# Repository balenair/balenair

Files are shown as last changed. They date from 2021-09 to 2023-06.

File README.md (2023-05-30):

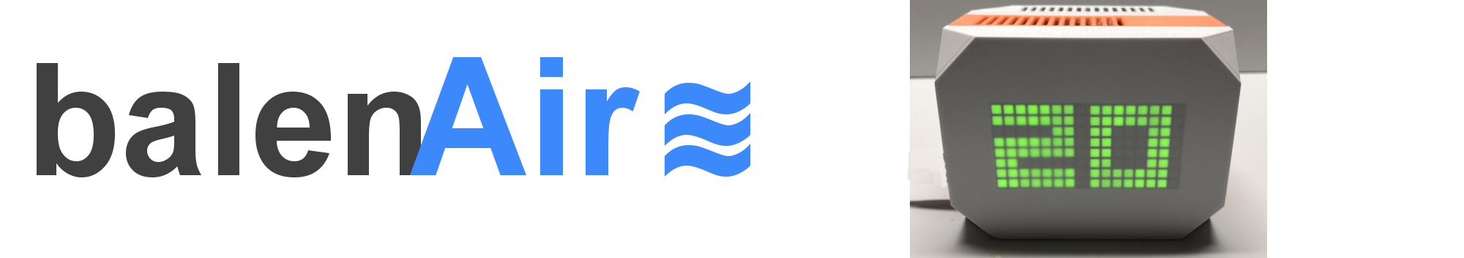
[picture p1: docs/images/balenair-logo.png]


**The IAQ is an attractive device you can easily build that measures the quality of your indoor air and also provides readable feedback on an integrated LED display and a web dashboard.**

## Highlights

- **Works with multiple sensors**: Choose among CO2, particulate matter, temperature/humidity, and VOC sensors based on your needs and budget.
- **Multiple display options**: Choose either a bi-color LED matrix or a multi-color LED bargraph.
- **Your data stays local**: Your data remains your own. It is stored locally and can be accessed by a built-in secure web dashboard.

## Setup and configuration

Start by assembling the hardware - see our parts list and assembly instructions in [the docs](./docs). Deploying the code to a fleet of one or more devices is as easy as clicking the button below:

balena deploy button (https://dashboard.balena-cloud.com/deploy?repoUrl=https://github.com/balenair/balenair)

## Documentation

Head over to [our docs](./docs) for detailed parts lists, options, building, installation and usage instructions, customization options and more!

## Motivation

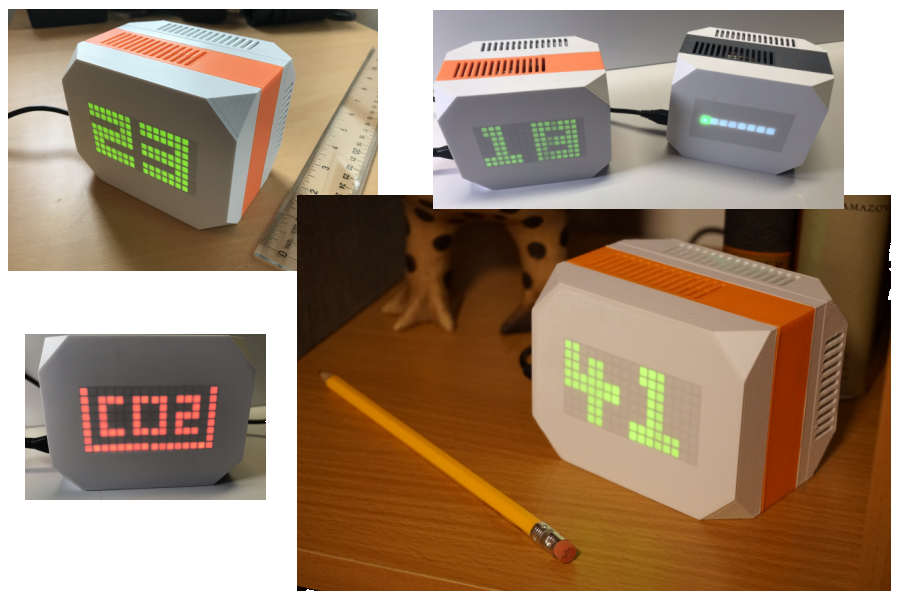
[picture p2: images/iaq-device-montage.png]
concept


balenAir is a great starter project for learning about IoT, environmental sensors, containers, and the balena platform. It is also a very functional and useful device, which stores all of your data locally, not in the cloud. Yet you can access this data anywhere via its built-in web server and secure VPN tunnel.

This open source project is in active development so if you have any feature requests or issues please submit them here on GitHub. PRs are welcome, too.

## The IAQ score
The IAQ device uses a combination of CO2, VOC, and particulate sensors to generate an indoor air quality score.  The standard IAQ device displays the score using an LED matrix on the front of the unit. The easy-to-remember score ranges from 0 (best air quality) to 99 (hazardous air quality).

### The sensors
The project consists of up to three sensors but only one is required. You can choose any or all depending on your needs and budget. The air quality score is comprised of a combination of readings from the available sensors. 

- Particulate sensors for smoke, dust, pollen and other tiny particles
- CO2 sensor for exhaled breath and burning fossil fuels
- Volatile Organic Compound (VOC) sensor for gasses emitted by solid and liquid products
- Temperature and humidity environmental sensors

Since all of the sensors utilize an I2C Qwiic connector, no soldering is required. See the [parts list](./docs/01-hardware-selection.md#choosing-your-sensors) in the documentation for more details on cost and availability of these sensors.

### The display

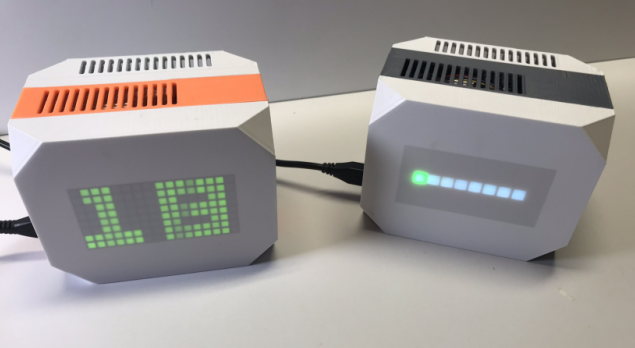
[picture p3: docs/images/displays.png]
IAQ displays


The standard display uses two 1.2" Bi-color 8x8 LED Matrix displays that cost about $16 each ($32 total). This display provides visual feedback of the air quality score and changes color as the score increases. A less costly option utilizes an eight segment multi-color LED bargraph that displays the air quality score as a horizontal graph that also changes color as the score changes. 

The standard matrix display requires some soldering to build. The bargraph LED version can be built without any soldering.

You can build a working IAQ device for as little as $50! See the parts list in the [Hardware Selection Guide](./docs/01-hardware-selection.md) for more details on cost and availability of the display parts.

### The case

We provide STL files so you can use a 3D printer to print a beautiful case for the IAQ.

The case consists of four interlocking layers that are held together by four M3 x 40mm hex socket head screws. The case accomodates any or all of the supported sensors, two different Raspberry Pis, as well either of the display options.

See [the documentation](./docs/05-case-printing-and-assembly.md) for more information about printing and assembly of the case.

### The software

All of our software is open source so you can inspect it in this repository before you decide to build or purchase a device. The system is built on the [balena](www.balena.io) IoT platform which ensures easy software updates, secure URL access, and ease of maintenance.

## Getting Help

If you're having any problem, please [raise an issue](./issues/new) on GitHub and we will be happy to help.

## Contributing

Do you want to help make IAQ better? Take a look at our [Contributing Guide](CONTRIBUTING.md). Hope to see you around!

## License

IAQ is free software, and may be redistributed under the terms specified in the license.

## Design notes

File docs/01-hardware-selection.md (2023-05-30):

# 1. Hardware selection

There are a number of options when it comes to selecting hardware for the IAQ. Cost, availability and performance are some factors to consider when choosing the parts below.

## Choosing your Pi

The IAQ runs on a Raspberry Pi, so you'll need one of the following compatible devices:

- A [Pi 3A+](https://www.raspberrypi.com/products/raspberry-pi-3-model-a-plus/) or [Pi Zero 2 W](https://www.raspberrypi.com/products/raspberry-pi-zero-2-w/) will fit in the custom case, so one of these is the best choice
- A [Pi 3B](https://www.raspberrypi.com/products/raspberry-pi-3-model-b/), [Pi 3B+](https://www.raspberrypi.com/products/raspberry-pi-3-model-b-plus/), [Pi 4](https://www.raspberrypi.com/products/raspberry-pi-4-model-b/), [CM4](https://www.raspberrypi.com/products/compute-module-4/?variant=raspberry-pi-cm4001000) or [CM3+](https://www.raspberrypi.com/products/compute-module-3-plus/) based system (Like the [balenaFin](https://www.balena.io/fin/)) will work fine but will not fit in the custom case.

(The IAQ is not compatible with the Pi Zero or first generation Pi)  

The IAQ is not particularly resource-intensive, so any of the supported boards above should work equally well. Note that currently the Pi Zero 2 W is only available without headers soldered in place. If you choose this device, you'll need to solder headers or wires onto the board. You could also try a "[solderless hammer header](https://shop.pimoroni.com/products/gpio-hammer-header?variant=35643318026)" although we have not tested these.

## Choosing your sensors

The sensors evaluate your air and return data that is used to deterime your air quality score. The IAQ utilizes the [big sensor block](https://github.com/alanb128/big-sensor) so supports any of the sensors listed [here](https://github.com/alanb128/big-sensor#currently-supported-sensors). However, you'll want to use a supported sensor that returns one or more of the following values:

- CO2
- eCO2
- temperature
- humidity
- pm100 env
- pm25 env

 Typically, one or more of the following sensors are used, depending on your budget and air quality analysis needs.

| Sensor | Detects | Description | cost (USD) | specifications (approx.) |
| --- | --- | --- | --- | --- |
| [PMSA003I](https://www.adafruit.com/product/4632) | Smoke, dust, dirt, pollen particles | laser-scattering type | $44.95 | 0.3-1.0,1.0-2.5, 2.5-10 Micrometer particles ([datasheet](https://cdn-shop.adafruit.com/product-files/4632/4505_PMSA003I_series_data_manual_English_V2.6.pdf)) |
| [SCD-40](https://www.adafruit.com/product/5187) | Exhaled breath and burning fossil fuels |  CO2 photoacoustic sensor CO2 (plus temp and humidity) | $44.94 | 400 - 2000 PPM ([datasheet](https://cdn-learn.adafruit.com/assets/assets/000/104/015/original/Sensirion_CO2_Sensors_SCD4x_Datasheet.pdf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)) |
| [SGP-30](https://www.adafruit.com/product/3709) | Gasses emitted by solid and liquid products  |  VOC (and eCO2) Hot-plate MOX sensor | $17.50 | eCO2 400-60,000 ppm, TVOC 0-60,000 ppb ([datasheet](https://cdn-learn.adafruit.com/assets/assets/000/050/058/original/Sensirion_Gas_Sensors_SGP30_Datasheet_EN.pdf)) |
| [ENS160](https://www.adafruit.com/product/5606) | Gasses emitted by solid and liquid products  |  VOC (and eCO2) MOX gas sensor | $21.95 | eCO2 400-65,000 ppm, TVOC 0-65,000 ppb ([datasheet](https://cdn-learn.adafruit.com/assets/assets/000/115/331/original/SC_001224_DS_1_ENS160_Datasheet_Rev_0_95-2258311.pdf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)) |

All of these sensors use the popular I2C protocol to communicate with the Pi and include [Qwiic](https://www.sparkfun.com/qwiic) connectors so you don't need to do any soldering to use these sensors.

The IAQ will automatically detect which sensors are present and caluclate the air quality score accordingly. If you connect the specified VOC sensor but do not have the specified CO2 sensor attached, the VOC sensor's eCO2 readings will be reported as the CO2 values. (eCO2 is generally less accurate than CO2 and requires proper calibration)

## Choosing your display

IAQ displays

Each IAQ device has a bright LED display so you can read your score from across a room. The score will be calculated and displayed even if your device is not connected to the internet. Regardless of the display type you choose, you can still obtain detailed sensor and air quality score readings from the built-in web dashboard.

### Two digit bi-color LED matrix

This is the most detailed display and also the most expensive. It utilizes two $15.95 [LED Square Pixel Matrix with I2C Backpack](https://www.adafruit.com/product/902) boards which require some light soldering to mount the display to the backpack. Recent versions of the backpack include a qwiic connector, but older ones will need to use angled headers, not the straight ones included with the boards. These should be right-angled male headers where the right angle occurs above the plastic strip [like these](https://www.amazon.com/Uxcell-a15062500ux0349-Single-40-pin-Breadboard/dp/B01461DQ6S/), NOT below the strip [like these](https://www.adafruit.com/product/1540). (A subtle difference but one type will fit in the case while the other will not!) 

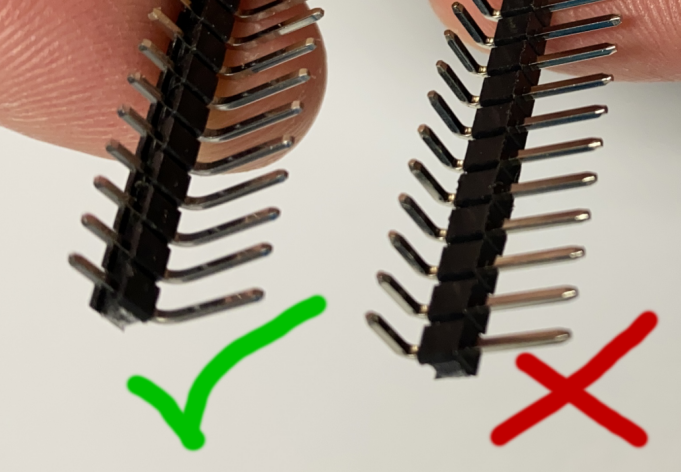
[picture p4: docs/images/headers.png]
headers


If you are not using our custom case, you can just use the headers that are included with the display boards. These displays can be mounted directly on posts in the custom case with no modifications required.

The matrix displays are driven via I2C and if they do not have qwiic connectors, will require two [Qwiic to female header](https://www.adafruit.com/product/4397) cables to connect to the Pi. 

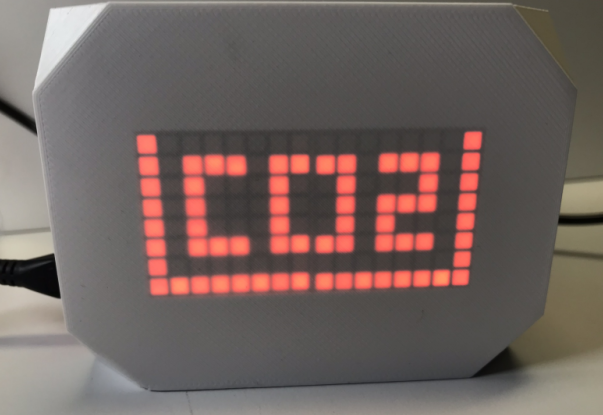
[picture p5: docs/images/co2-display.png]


In addition to displaying the two digit score, these displays can optionally show the most dominant pollutant type (CO2, PM10, PM2.5, VOC) detected by the sensors, as well as some rudimentary animations. The displayed information will change color from green to orange to red depending on the score.

To summarize the parts for this option:

- Two [LED Square Pixel Matrix with I2C Backpack](https://www.adafruit.com/product/902)

- One [50mm QT to QT cable](https://www.adafruit.com/product/4399) to connect the first LED to the second.

If the backpack does not include qwiic connectors:

- One strip of [angled male headers](https://www.amazon.com/Uxcell-a15062500ux0349-Single-40-pin-Breadboard/dp/B01461DQ6S/)

- One additional [Qwiic to female header](https://www.adafruit.com/product/4397) cable to connect the second backpack to the multiport

- One SparkFun Qwiic multiport, available [here](https://www.adafruit.com/product/4861) and [here](https://www.sparkfun.com/products/18012)

### Eight LED multi-color bargraph

This type of display is less detailed than the two digit matrix (the score is broken into eight segments with each one representing 12.5 points) and can't display the pollutant type. It does however have multiple color indications and can be configured in three different display formats. No soldering is required with this option

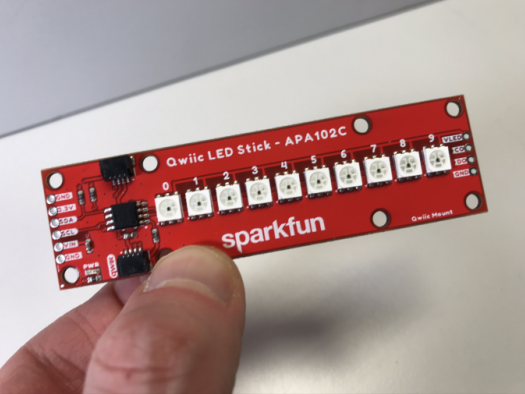
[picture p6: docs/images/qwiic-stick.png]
Qwiic Stick


This display is $11 or about a third the cost of the LED matrix and is based on the 10 LED [SparkFun Qwiic Stick](https://www.sparkfun.com/products/18354). (We only use eight of the ten LEDs that neatly fit the IAQ's case window.) In addition to one of these displays, you'll need a [100mm QT to QT cable](https://www.adafruit.com/product/4210) to connect it to the IAQ.

With this option, you'll also need a SparkFun Qwiic multiport, available [here](https://www.adafruit.com/product/4861) and [here](https://www.sparkfun.com/products/18012)

## Remaining parts list

With either display, you'll also need the following parts:

- One [Qwiic to female header cable](https://www.adafruit.com/product/4397) to connect the display to the Pi

- One [200mm QT to QT cable](https://www.adafruit.com/product/4401) to connect the display to the first sensor.

- One [100mm QT to QT cable](https://www.adafruit.com/product/4210) to connect the first sensor to the second sensor. Only required if you have two or three sensors!

- Another [100mm QT to QT cable](https://www.adafruit.com/product/4210) to connect the second sensor to the third sensor. Only required if you have three sensors!

Note that there are some additional hardware requirements if you will be using the custom 3D printed case - see [this section](05-case-printing-and-assembly.md) for details.

### NEXT
[2. Hardware Setup](02-hardware-setup.md)

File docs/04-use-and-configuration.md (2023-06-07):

# 4. IAQ usage and configuration

After you have put together the hardware, installed the software and (optionally) assembled the case, you can power on the IAQ by plugging a standard 5V/2.5A or greater power transformer into the Pi's micro USB port. After about a minute, the air quality score should be visible on the display. Sensor readings are taken approximately once per minute.

## The IAQ score

The easy-to-remember IAQ score ranges from 0 (best air quality) to 99 (hazardous air quality). Each sensor has a range of readings that are categorized as "good", "moderate", or "unhealthy". These rages are based in part on various governmental standards, such as [the EPA](https://www3.epa.gov/region1/airquality/pm-aq-standards.html) and others.

| Reading | Description | Sensor Type | good range (0 - 50) | moderate range (51 - 74) | unhealthy range (75 - 99) |
| --- | --- | --- | --- | --- | --- |
| PM2.5 | Smoke, dust, dirt, pollen | PMSA003I | 12 - 34 ug/m3 | 35 - 54 ug/m3 | 55+ ug/m3 |
| PM10 | Dust, smoke, exhaust, tiny particles | PMSA003I | 0 - 53 ug/m3 | 54 - 149 ug/m3 | 150+ ug/m3 |
| CO2 | Exhaled breath and burning fossil fuels | SCD-40 | 400 - 999 PPM | 1000 - 1999 PPM | 2000+ PPM |
| VOC | Gasses emitted by solid and liquid products  | SGP-30 | 0 - 499 PPB | 500 - 999 PPB | 1000+ PPB |

**The final score displayed by the device is the highest score from among all the available sensors.**

## Display options

### LED Matrix display
By default, the display will constantly show the score if the value is below 50. Once the score is over 50, an icon representing the dominant pollutant will alternate on the display along with the score. These icons are:

- "CO2" representing carbon dioxide (CO2)
- "PM1" representing PM 10 (particulate matter 10 micrometers or less in diameter)
- "PM2" representing PM 2.5 (particulate matter 2.5 micrometers or less in diameter)
- "VOC" representing Volatile Organic Compunds (VOC)

When you first power on the device, it will cycle through the connected sensors and briefly display the icon above for each one found. If no sensors are found, the display will show "??". 

You can change the default behavior of the icon display by setting the following [device variables](https://www.balena.io/docs/learn/manage/variables/#device-variables) in your balenaCloud dashboard:

`ALERT_LEVEL` changes the threshhold value for alternating the display of the pollutant. The default value is 50 but you can change it by setting this value. 

`ALERT_MODE` has a default value of `1`, which causes the display to alternate the pollutant icon when the score exceeds the `ALERT_LEVEL` defined above. Changing this value to `0` will cause the score to always be displayed and never display a pollutant icon regardless of the `ALERT_LEVEL`. Setting this value to 2 will always show an alternating pollutant icon regardless of the `ALERT_LEVEL`.

Note that these variables will not initially be present in the dashboard, you will have to add them if you want to change their value. If they have not been added, or you delete them after previously adding them, they will revert back to the default values mentioned above.

The display changes color based on the score as follows:

| Score range | Description | LED display color | 
| --- | --- | --- |
| 0 - 49 | Good air quality | green |
| 50 - 74 | Moderate air quality | orange |
| 75 - 99 | Unhealthy air quality | red |

### LED bargraph display

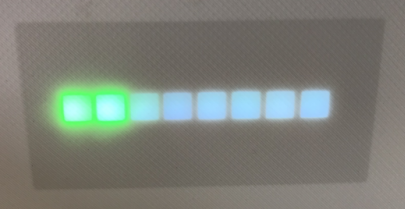
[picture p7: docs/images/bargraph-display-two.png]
Bargraph


By default the bargraph display will illuminate a segment from left to right based on the IAQ score, with each segment representing 12.5 points. The segments will be lit according to the color scheme shown above for the matrix display. Any unused segments to the right will be slightly illuminated in white. To eliminate the white segments, set the device variable `BAR_MODE` to `0`.

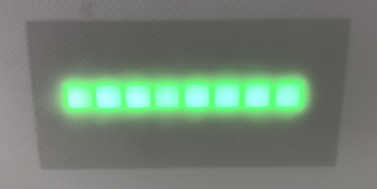
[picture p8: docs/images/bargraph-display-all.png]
Bargraph


If you set the `BAR_MODE` to `2` all of the LED segments will always be illuminated in either green, yellow, or red depending on the IAQ sore as shown above. 

To reset the display to the default mode, set `BAR_MODE` to `1` or delete the variable.

If the score is zero and you are using display mode 2, no LED segments will be illuminated. To force the leftmost LED segment to be lit even if the score is zero, set the `ZERO_BAR` variable to a value of `1`.

Upon initial startup, if no sensors are detected the bargraph display will show alternating red and green segments.

## The IAQ dashboard
The IAQ dashboard is a pre-built [Grafana](https://grafana.com/grafana/) dashboard that shows you the current and historical values from all of your sensors as well as the air quality score over time. If you are on the same network as the device, you can browse to IAQ.local or to the local IP address of the device (which you can find on its balenaCloud dashboard) to see the dashboard. If you want to enable access to the IAQ dashboard from outside your network, you can enable the "Public Device URL" from your balenaCloud dashboard and then click the icon next to that switch to view its public URL.

To modify the IAQ dashboard or add your own, you can log into Grafana with the arrow icon in the lower left of the screen. The default username and password are admin/admin. If you want to experiment with making changes to the dashboard, you can copy the default dashboard and make changes to it so you don't risk making inadvertent alterations.

See the [Grafana documentation](https://grafana.com/docs/grafana/next/panels/working-with-panels/) for more information about modifying/designing dashboards.

## Other configuration options

### Logging
By default, the IAQ service will only send certain information to the logs. If you want to see more or less detail in the logs, you can set the `LOG_LEVEL` device variable. The default value is `WARNING` but setting to `DEBUG` or `INFO` will provide more logging detail. To see fewer logging details, you can select `ERROR` or `CRITICAL` as well.

### External MQTT

You can have the balenAir publish to an external MQTT broker or service, such as the [balenAir Aggregator](https://github.com/balenair/aggregator). To initiate this, set the `AGG_ADDRESS` variable to the address of the external MQTT broker - this works best if all devices are on the same local network. See the Aggregator repo for more details on other setup options. You can also specify `AGG_USERNAME`, `AGG_PASSWORD`, and `AGG_PORT` (default is 1883) as well. To stop publishing, delete the `AGG_ADDRESS` variable.

## VOC calibration
The [SGP30 VOC sensor](https://www.adafruit.com/product/3709) is a type of gas sensor that needs to be calibrated to provide reasonably accurate measurements. The balenAir no longer stores a baseline for this sensor, so see the details [here](https://learn.adafruit.com/adafruit-sgp30-gas-tvoc-eco2-mox-sensor/circuitpython-wiring-test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) regarding its default calibration process.

### NEXT
[Case printing & assembly](05-case-printing-and-assembly.md)

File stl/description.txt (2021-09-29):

Files for printing the four pieces that make up the custom case.

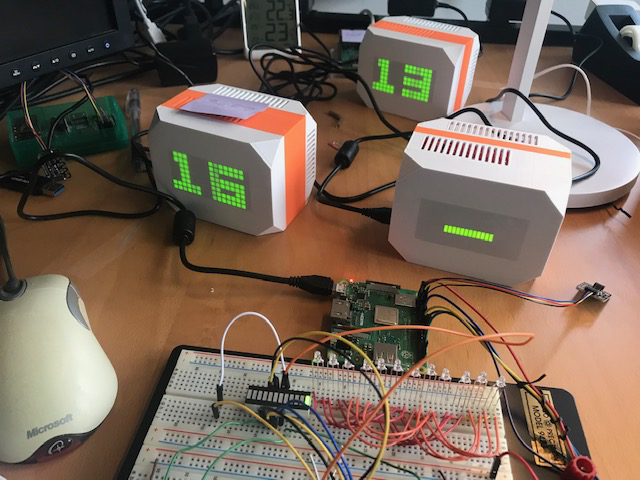
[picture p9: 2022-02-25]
images/three-iaq-displays.png

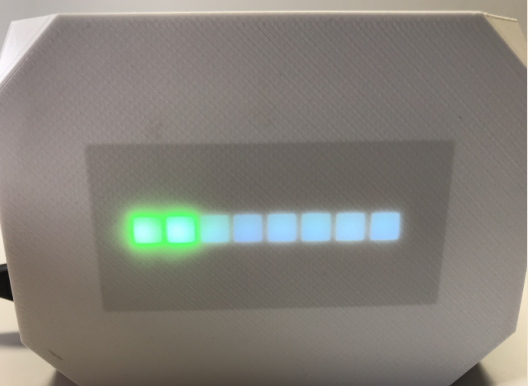
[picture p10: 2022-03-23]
docs/images/bargraph-1.png

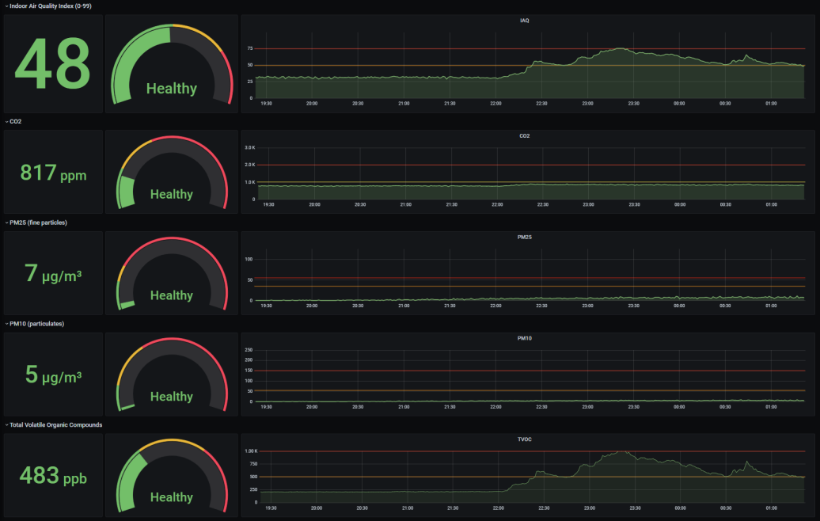
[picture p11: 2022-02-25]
docs/images/dashboard.png

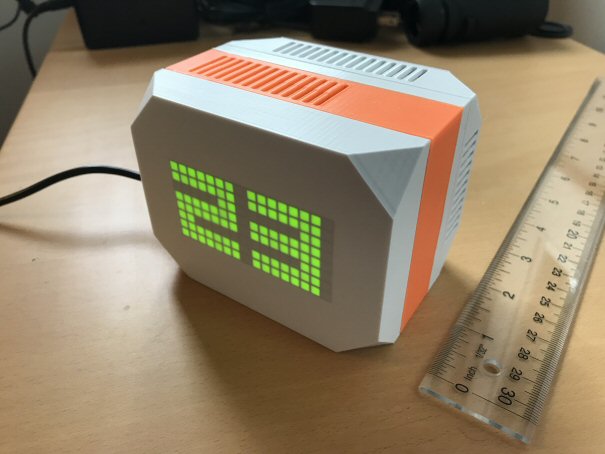
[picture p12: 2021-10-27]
images/unit2.jpg

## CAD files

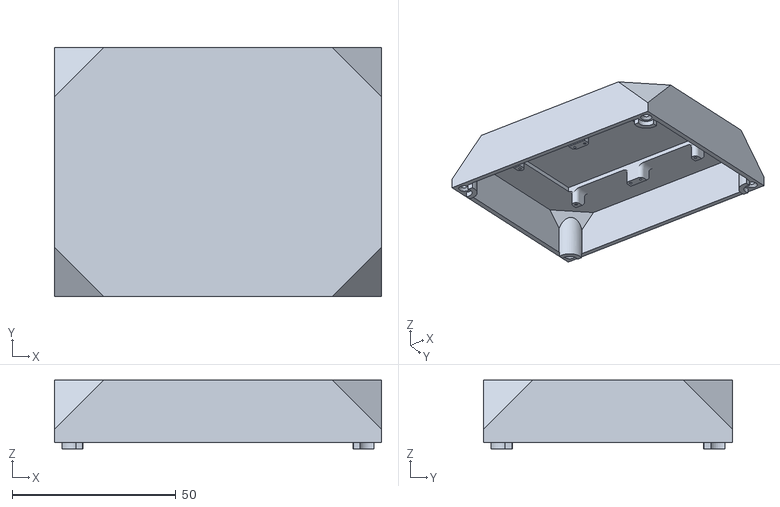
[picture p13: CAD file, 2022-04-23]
stl/front.stl
100.0 x 76.0 x 21.0

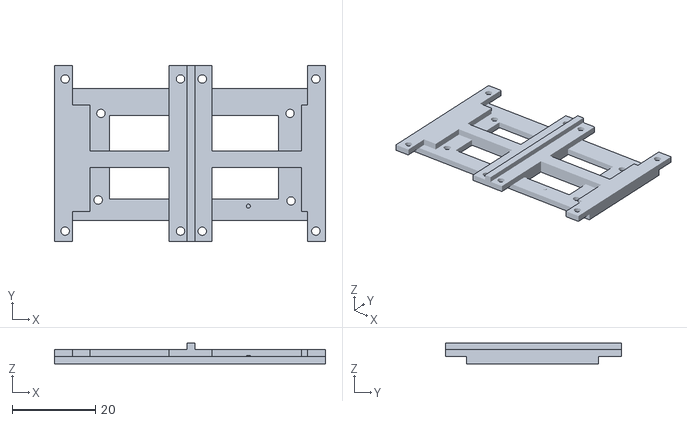
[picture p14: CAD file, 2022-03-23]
stl/bargraph-bracket-back.stl
65.0 x 42.2 x 5.00

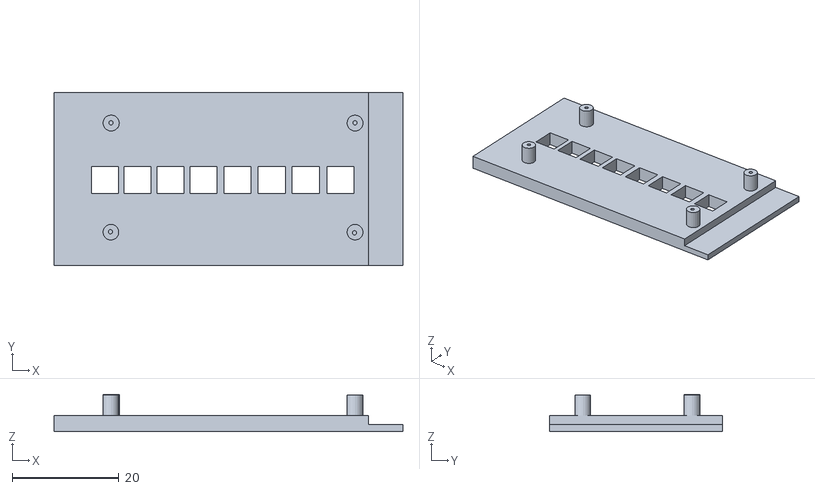
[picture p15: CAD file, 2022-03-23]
stl/bargraph-bracket-front.stl
65.5 x 32.5 x 6.96

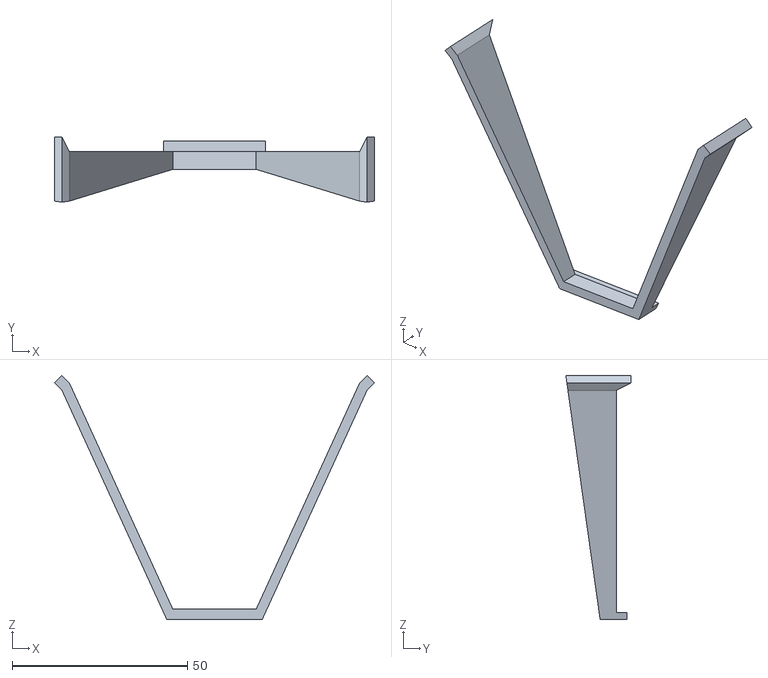
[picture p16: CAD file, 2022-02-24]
stl/stand.stl
91.4 x 18.7 x 69.7

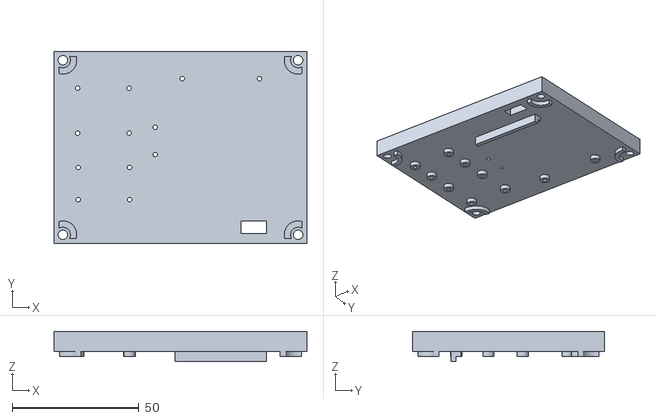
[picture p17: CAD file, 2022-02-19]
stl/insulate_sense.stl
100.0 x 76.0 x 12.0

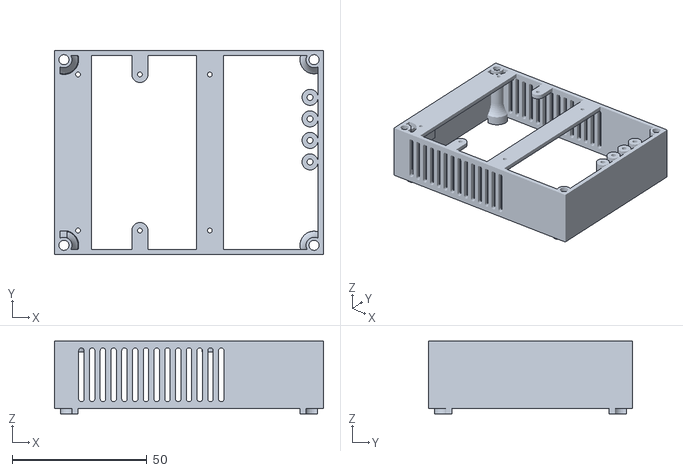
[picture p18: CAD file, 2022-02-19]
stl/pi_ring.stl
100.0 x 76.0 x 27.0

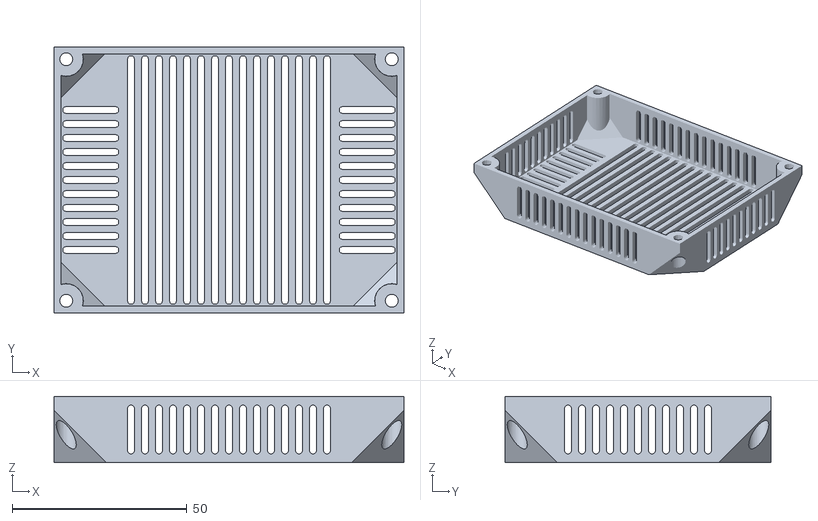
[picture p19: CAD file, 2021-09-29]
stl/back.stl
100.0 x 76.0 x 19.0

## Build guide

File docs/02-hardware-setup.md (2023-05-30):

# 2. Hardware setup

Once you have all of your parts gathered, it's a good idea to walk through this assembly guide to get familiar with how everything is connected together. Even if you will be using the 3D printed case, you may want to connect everything together and install the software before placing everything in the case. All of the connections are modular so it's easy to disconnect all of the parts and re-connect them again later inside the case. Make sure your Pi is powered off during the hardware setup!

## Connecting the sensors

All of the sensors utilize the I2C data bus and contain Qwiic connectors, so they can all be connected together rather easily. 

Start by connecting the female jumpers on one end of the "150 mm Qwiic to 4 pin female cables" to the Raspberry Pi. Note the pin assignments based on the wire color using the diagram below:

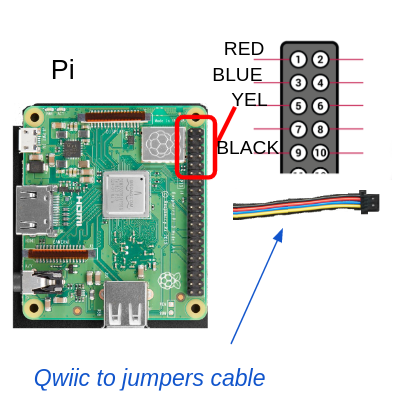
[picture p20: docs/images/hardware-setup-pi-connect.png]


- The red wire goes to pin 1 (3v)
- The blue wire goes to pin 3 (SDA)
- The yellow wire goes to pin 5 (SCL)
- The black wire goes to pin 9 (Gnd)

The connector at the other end of the cable connects to either the first matrix display or any one of the four ports on the multiport connector if required. Now connect one end of the "200mm QT to QT cable" to any of the three remaining empty ports on the multiport connector or the second matrix display. This is the long cable that will be used to connect to the first sensor since when mounted in the case, the multiport will be somewhat far from this sensor. The other end of this cable can be connected to the first sensor. When mounted in the case, the first sensor is physically the blue rectangular particulate sensor. However, you can connect the sensors in any order you please. Use the remaining "QT to QT" cables to connect any remaining sensors you may have in a daisy chain fashion as shown below:

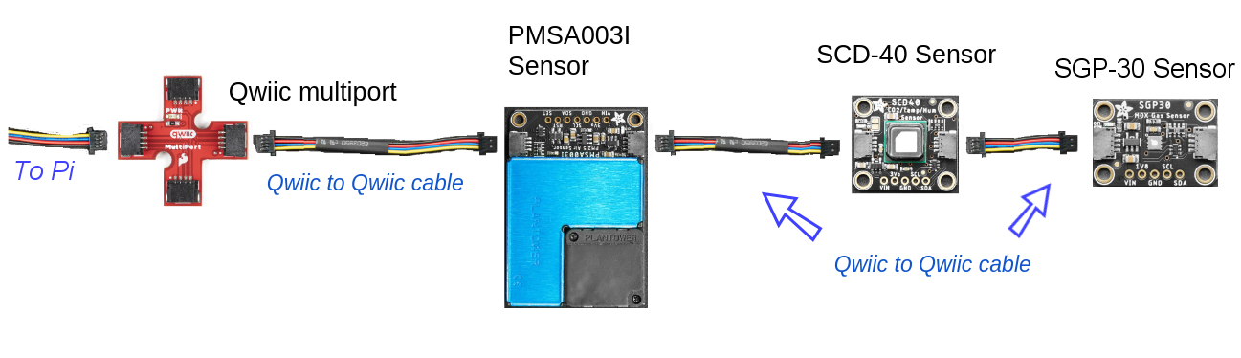
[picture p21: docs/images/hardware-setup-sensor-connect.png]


## Connecting the display

### LED matrix assembly

If you're using the two LED matrix boards, you'll first need to solder each LED matrix to its backpack as described [here](https://learn.adafruit.com/adafruit-led-backpack/bi-color-8x8-matrix-assembly). 

You'll also need to change the I2C address of one of the displays. using [this guide](https://learn.adafruit.com/adafruit-led-backpack/changing-i2c-address), solder together the A0 pads of one display to change its address from 0x70 to 0x71. This will be the left digit when facing the front of the two displays.

If your backpack does not have qwiic connectors:

Solder the four pin male headers to each backpack. If you will be using the standard case, you must use the angled headers as specified in the parts list, not the straight headers included in the backpack kit. Make sure the headers are angled outwards as shown below:

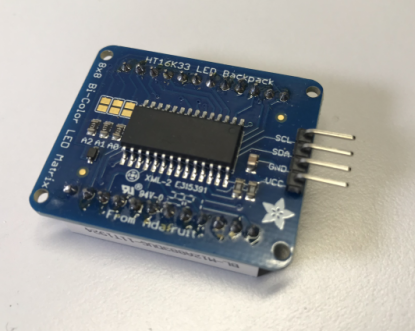
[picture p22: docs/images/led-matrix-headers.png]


Finally, use the two remaining "Qwiic to female jumper" cables to connect the two displays to the two open ports on the multiport connector. The jumper cables connect to the headers as follows:

- The yellow jumper connects to SCL
- The blue jumper connects to SDA
- The black jumper connects to GND
- The red jumper connects to VCC

### LED bargraph display

Connecting this type of display is easy: simply connect one end of a 100mm Qwiic connector to one of the jacks on the LED stick. Connect the other end to a free port in the 4-way Qwiic multiport connector.

NOTE: This display has a power LED that may be visible through the IAQ case. You should disable this LED by scratching off the trace between the LED pads (not the VLED pads!) on the back of the circuit board. See the [Qwiic Stick guide](https://learn.sparkfun.com/tutorials/qwiic-led-stick---apa102c-hookup-guide#hardware-overview) for more details.

### Next
[3. Software setup](03-software-setup.md)

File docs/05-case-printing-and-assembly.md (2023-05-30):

# 5. Case printing and assembly

The IAQ has a lovely and easy-to-print 3D case that fits the standard parts listed in the hardware list.

## Hardware required

To assemble the printed parts, you'll need the following:

- eight (8) M1.4 x 5mm self-tapping screws to mount the display (plus four more if using the LED bargraph)
- four (4) M2 x 6mm pan head screws for mounting the Pi 3A+ or four (4) M2 x 10mm screws for Pi Zero 2W
- two (2) M2 x 10mm pan head screws for mounting the multiport connector
- two to four (2 - 4) M2 x 12mm pan head screws to mount EACH sensor (up to 10 screws total)
- four (4) M3 x 40mm hex socket head screws to secure the case

The screw lengths specified above for the M2 screws are minimum values. Somewhat longer screws can always be used instead; shorter screws may not work well. In a pinch, #2 screws of similar length may be substituted for the M2 screws although they may be a bit tight.

## Printing

The IAQ case consists of four pieces that can be printed using a standard consumer 3D printer. The files for printing these pieces are in the `stl` folder.



We have tested these pieces by slicing them using Ultimaker Cura 4.11; Each piece should be rotated 180 degrees for printing. We used an infill density of 20%, which the printing characteristics below are based on.

## Front piece

The front panel holds the LED/backpack assemblies. Each assembly sits on a set of four posts. Use M1.4 x 5mm screws to secure the displays to the posts. The backpack that is set to the 0x71 address by the solder pad blob should be on the right when looking at the back of the face plate. The angled headers should face upwards towards the top of the front piece. (At this point, you can establish which orientation is the top, as the sides are both the same.) TIP: attach the qwiic connectors (or female wire headers) before inserting the displays onto the posts.

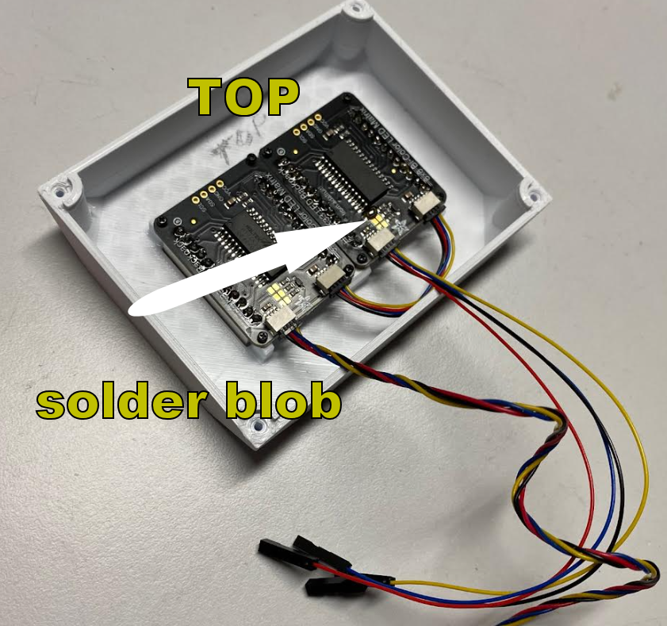
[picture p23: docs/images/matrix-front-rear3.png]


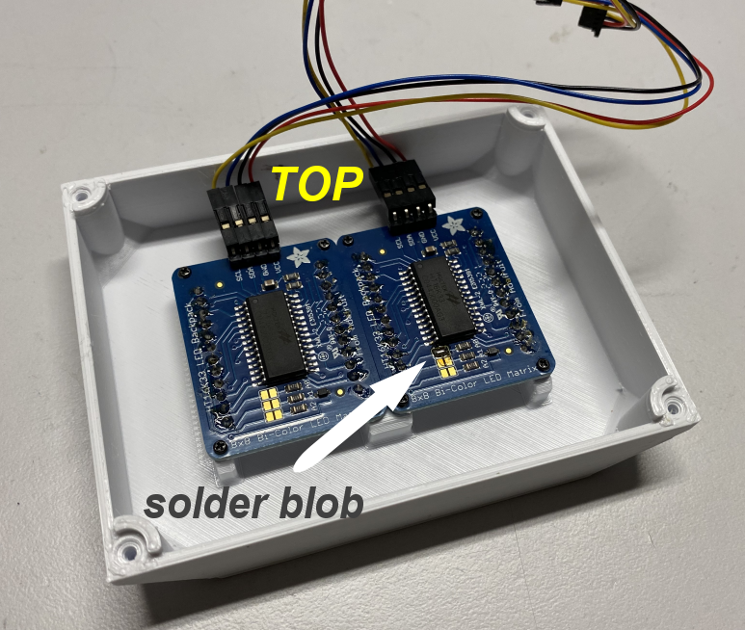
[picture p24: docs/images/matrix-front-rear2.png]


Printing tips: Note that the first layer is only one layer thick for the display window portion of the front piece. Since that adds a lot of surface area on the bed, you can probably get by with a skirt instead of a brim for this part. We suggest printing this piece in some version of white so that the window does not interfere with the LED colors. (Our standard has been to print the front and back in white, and the middle pieces in a contrasting color such as orange.) Typical printing characteristsics: 28g/9.4m of filament; 4:06 print time.

### LED Bargraph
If you are using the LED bargraph, also print the `bargraph-bracket-front.stl` and `bargraph-bracket-back.stl` pieces. Start by laying the front bracket piece (with the square cutouts) flat with the posts facing up and the indented area on the left. Then place the Qwiic Stick upside down onto the four posts as shown below:

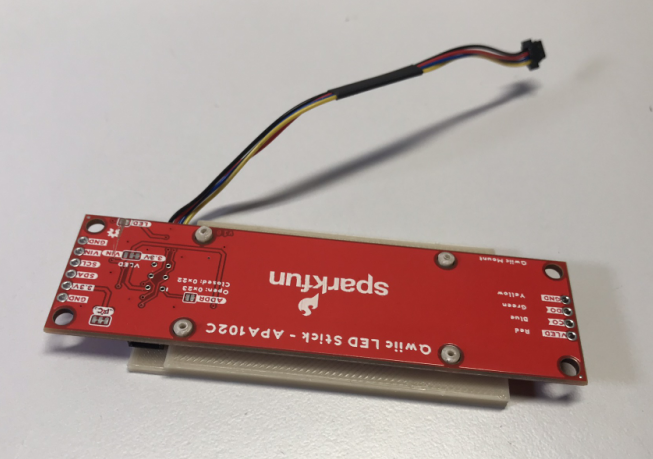
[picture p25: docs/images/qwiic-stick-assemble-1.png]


Next, place the back bracket piece on top of the four posts fron the front piece, lining up the four holes. Note that the wider side of the back bracket (with the black marker in the image below) should be on the right. Use four M1.4 x 5mm self-tapping screws to secure the two parts of the bracket together with the Qwiic Stick in between.

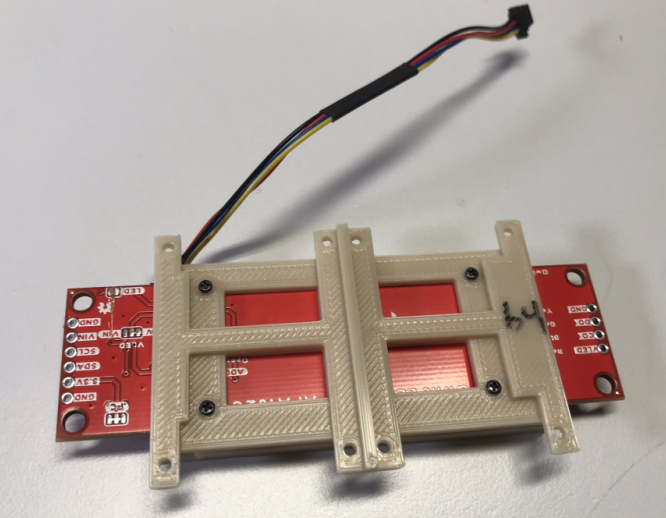
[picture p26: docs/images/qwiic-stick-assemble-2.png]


Now use eight M1.4 x 5mm self-tapping screws to attach the bracket assembly to the front case piece, noting the orientation shown below:

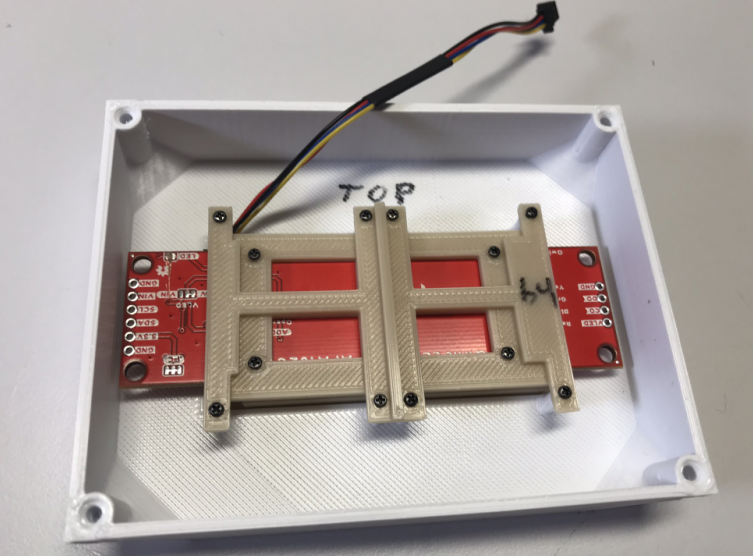
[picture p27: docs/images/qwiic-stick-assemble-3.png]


## Pi Ring
The `pi_ring` holds the Raspberry Pi 3A+ or Zero 2 W in place. 

### Pi 3A+
Use four M2 screws to mount the Pi in the provided holes and secure with nuts oriented as shown below. Make sure the micro USB port lines up with the hole on the side of the pi ring.

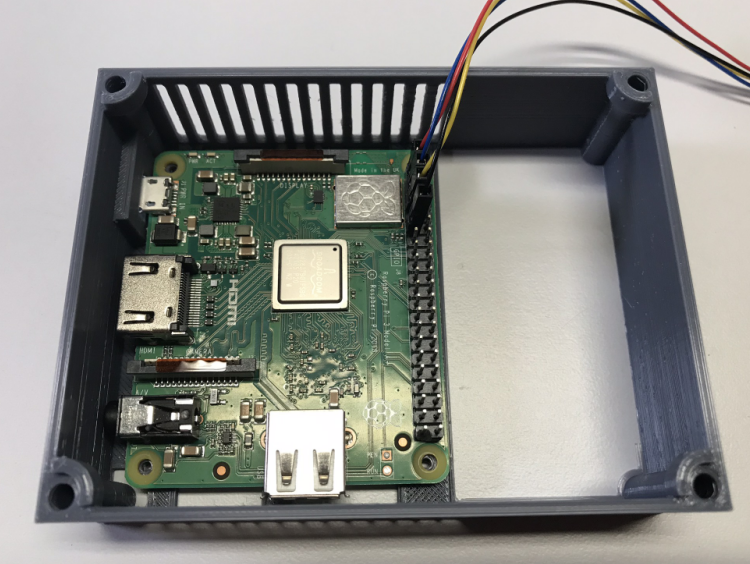
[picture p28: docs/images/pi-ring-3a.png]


### Pi Zero 2W
Note the four cylidrical spacers that print along the right wall of the part. These are used to properly mount a Pi Zero 2 W - you can ignore or discard them if using a Pi 3A+. 

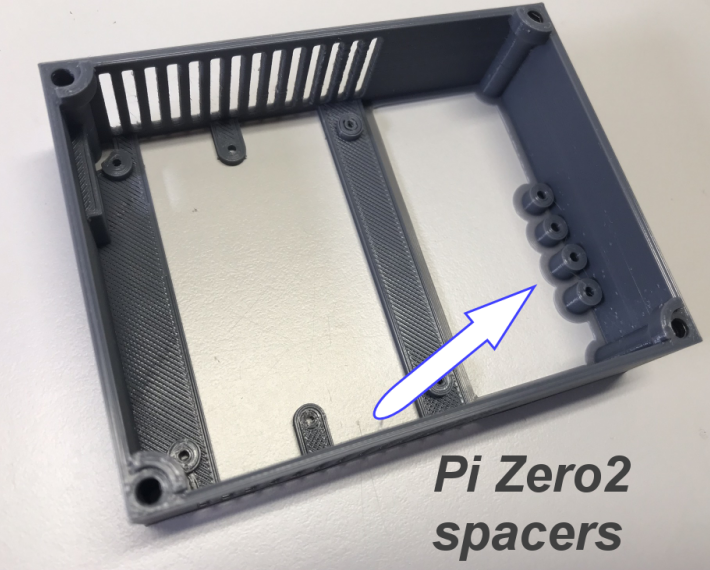
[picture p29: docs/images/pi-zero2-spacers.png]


To mount a Zero 2 W, remove the spacers and place them on the screw holes as shown below. The short spacers go closest to the wall with the hole, while the longer spacers go on the two midway tabs.

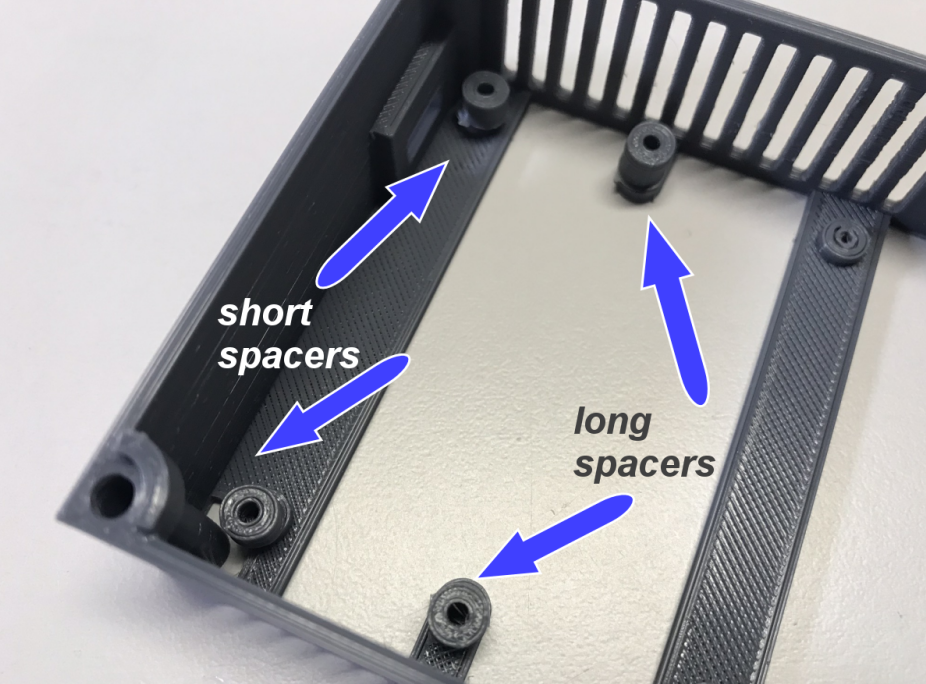
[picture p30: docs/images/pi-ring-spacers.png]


Mount the Pi Zero 2 inverted onto the spacers as shown below and secure with longer screws and nuts.

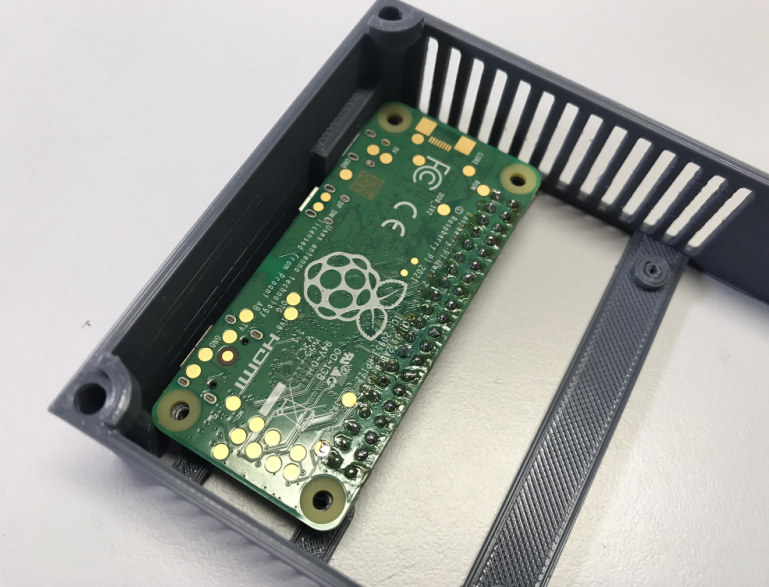
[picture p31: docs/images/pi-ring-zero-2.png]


Printing tips: This piece does not have a lot of bed surface area, so a brim is recommended. Printing characteristics: 27g/9.04m of filament; 5:15 print time.

## Insulate sense
The `insulate_sense` piece is used to mount the sensors and insulate them from the heat of the Pi. There is a small opening at the bottom of this piece to feed a Qwiic connector and cable through to the other side to attach to the first sensor (usually the particulate unit). The side opposite the sensor mounts has two holes to attach the Qwiic multiport connector (if needed) with M2 x 10mm pan head screws and optionally nuts.

There are mounting holes in the posts for all sensors. You can use two, three, or four M2 screws to attach each sensor. For extra stability, use one or more 12mm screw with a nut on the other end per sensor. The bottom of the particulate sensor "sits" on a small shelf. TIP: Tape the blue part of the particulate sensor to the circuit board with a small amount of electrical tape to keep it from sliding around. (Make sure not to cover any of the venting holes on the right of the sensor though!) You can daisy chain the sensors together using various length Qwiic connector cables. The image below shows the location for each sensor:

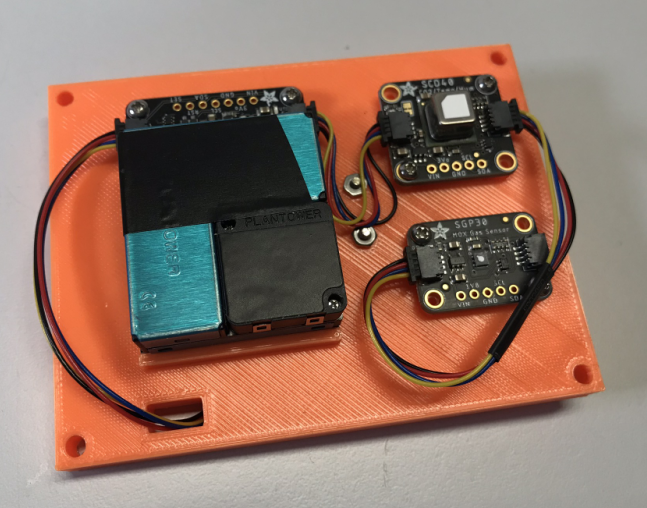
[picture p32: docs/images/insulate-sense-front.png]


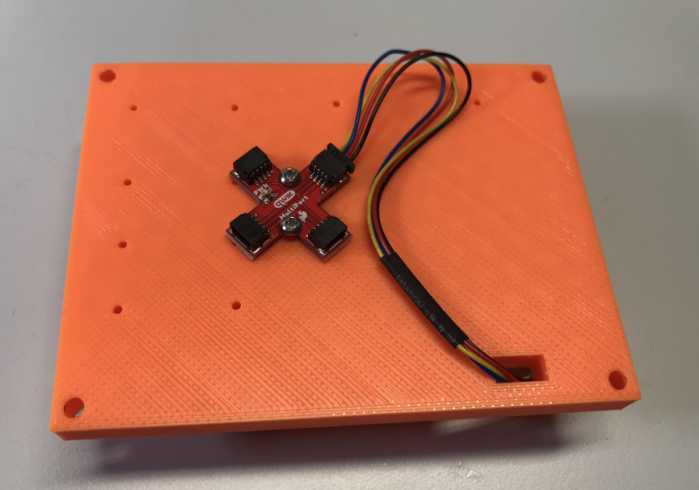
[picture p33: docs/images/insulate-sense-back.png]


Printing tips: This piece has a good amount of surface area on the bed, so a skirt may be sufficient. Printing characteristics: 31g/10.36m of filament; 3:42 print time.

## Back
The back of the unit provides protection and airflow for the sensors. All four pieces are held together by inserting four M3 x 40mm hex socket head screws through the back piece and attaching to the screw holes in the front piece. These screws should not thread into any piece other than the front - they should move freely until they hit the holes in the front. Since the front three pieces are interlocking, you can sandwich them together (being careful not to crimp any wires!) before placing the back piece on. You may need to start the threading on the front piece by inserting a small wood screw and rotating it a few turns.

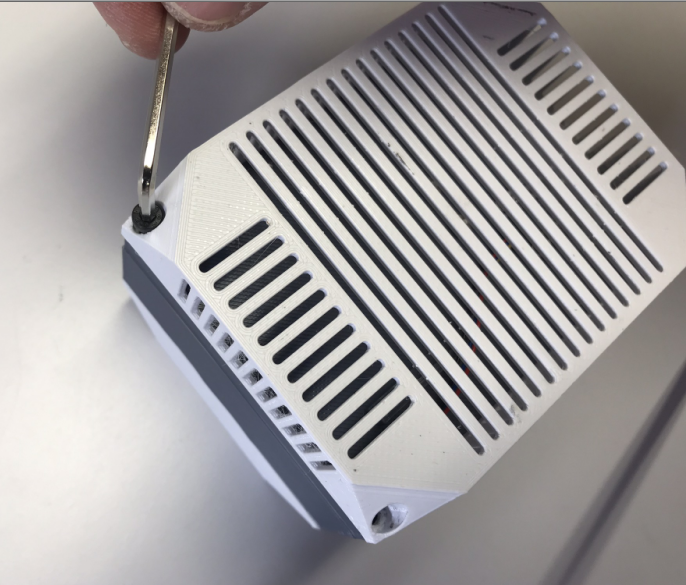
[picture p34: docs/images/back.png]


Printing tips: This piece has a limited amount of bed surface area, so a brim is recommended. In addition, you should enable the "generate support" option for placement "everywhere" and a support overhang angle of "45". Printing characteristics: 25g/8.44m of filament; 5:09 print time.

## stand

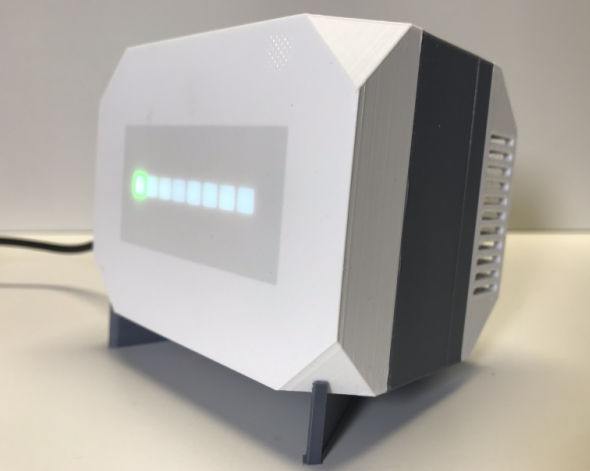
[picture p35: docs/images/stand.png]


The optional stand is a small angled platform for your IAQ device to sit on, which tilts it slightly upward for an improved viewing angle. When slicing this piece, it's best to rotate it forward 90 degrees and then select your "lay flat" option. Using a brim is also recommended.

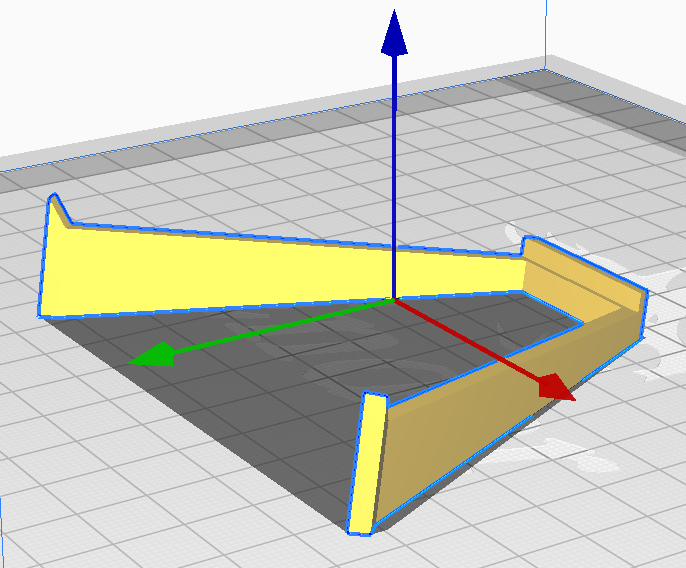
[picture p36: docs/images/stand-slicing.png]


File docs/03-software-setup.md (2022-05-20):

# 3. Software setup

Now that you have your hardware set up and connected, it's time to install the software...

At a minimum, you'll need software to flash the SD card that will be inserted into the Raspberry Pi. We recommend [balenaEtcher](https://balena.io/etcher).

There are three main ways to deploy the software to your device...

## The open fleet option
If you want the simplest software deployment and automatic updates for your device, choose this option. An open fleet is a group of devices that all run the same code that anyone can join. We make it easy to join open fleets on balenaHub, our platform for IoT users to exchange resources. To join your device to the IAQ open fleet, click here. (coming soon!)

Next click on the "get started" button and choose your model of Raspberry Pi from the dropdown list. For "Network Connection" choose "WiFi + Ethernet" and enter your WiFi SSID and password. (Note: these credentials are only stored inside the file you will be downloading and are not saved anywhere else.) Now, click the "Flash" button which will open balenaEtcher (if previously installed) and guide you through flashing the image to your microSD card.

### Notes about open fleets
- You don't need a balenaCloud account (free or paid) to join an open fleet

- The "fleet owner" for this open fleet is balenAir itself

- Your device's sensor data is potentially visible to the fleet owner, but not other members of the fleet

- balenAir does not save or view your sensor data except as needed for troubleshooting purposes initiated by a user

- If you want a private fleet (where you will be the fleet owner) choose one of the other two options below

## One-click deploy option
This option allows you to deploy and configure the IAQ with the single click of a button. It will create a new private fleet in your balenaCloud account. If you don't already have a free balenaCloud account, it will prompt you to create one. Use the button below to get started:

balena deploy button (https://dashboard.balena-cloud.com/deploy?repoUrl=https://github.com/balenair/balenair)

sdcard

Once your application has been created you'll need to add a device to it:

1. Add a device to the application by clicking the "add device" button. Don't forget to add WiFi credentials here if applicable!
2. Download the OS and flash it to your SD card with [balenaEtcher](https://balena.io/etcher)
3. Power up your device and check it's online in the dashboard!

The IAQ application will start downloading as soon as your device appears in the dashboard.

## Balena CLI option

This is the more advanced approach for deploying applications to balena powered devices. Choose this option if you want to customize or modify the code before deploying to your device. You'll need to download and install the [balena CLI tools](https://github.com/balena-io/balena-cli/blob/master/INSTALL.md). See the balena [Getting Started Guide](https://www.balena.io/docs/learn/getting-started/raspberrypi4-64/python/) for more details.

## Having trouble?

If you are running into issues getting your IAQ software running, please try the following:
1. Check the support and troubleshooting guide for common issues and how to resolve them. (coming soon!)
2. Post in the [forums](https://forums.balena.io/) for help from our growing community.
3. [Create an issue](https://github.com/balenair/balenair/issues) if you find your issue may be a bug or problem with the IAQ software.

### NEXT
[4. Use and configuration](04-use-and-configuration.md)

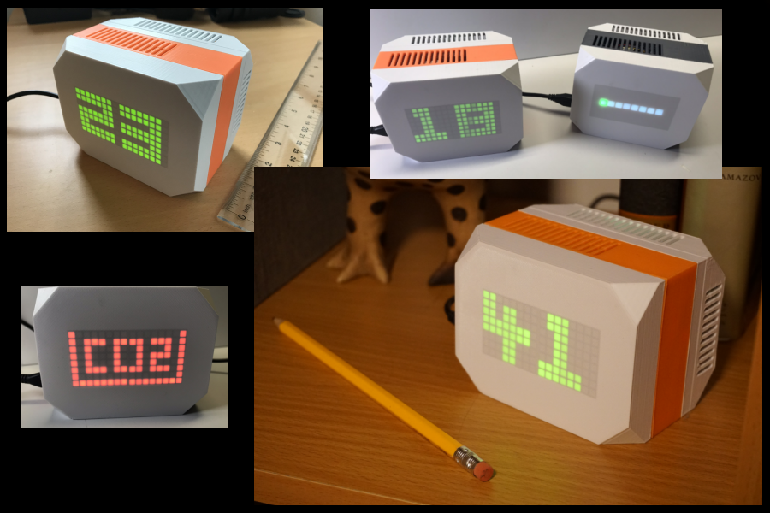
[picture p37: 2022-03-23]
docs/images/iaq-device-montage.png

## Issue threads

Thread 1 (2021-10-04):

Update case design to have positive location between slides

chrisys, 2021-10-04:
Consider implementing a lip/ridge around the edges of the layers so they interlock with each other, this would close visible gaps and allow for easier assembly as the layers would align even before the screws are added.

Closed 2022-02-19.

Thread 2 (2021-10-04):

Add 'feet' to the 3d printed model to allow for better ventilation

chrisys, 2021-10-04:
Investigate to see if we can add feet - probably to the Pi ring and insulate layers, to hold the case away from the surface it's sitting on allowing for better ventilation without having to add feet afterwards.

chrisys, 2022-02-24:
Addressed this with a stand in [2e59349](https://github.com/balena-io-playground/balena-iaq/commit/2e59349e9059f567c8c0b05d70451bd779bdea71) instead

Closed 2022-02-24.

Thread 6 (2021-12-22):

Test alternative pollutant labelling

chrisys, 2021-12-22:
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

Try the above layout for the pollutant labelling to see if it's more/less clear

alanb128, 2022-02-15:
Also try changing the order that the matrices update for a full wipe effect.

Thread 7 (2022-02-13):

Additional case modifications

alanb128, 2022-02-13:
- Allow for a Pi Zero 2W option to fit in same spot as 3A+
- Thermal improvement for accurate temperature readings
- Options for a different display front, like PCB with bar graph (needs more discussion)

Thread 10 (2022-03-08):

Confirm PM10 is PM10 and not PM 100

alanb128, 2022-03-08:
https://github.com/balena-io-playground/balena-iaq/blob/master/iaq/iaq.py#L759

The PM sensor manufacturer uses this line to display readings:
print("PM 1.0: {0} PM2.5: {1} PM10: {2}".format(aqdata["pm10 standard"], aqdata["pm25 standard"], aqdata["pm100 standard"]))

So is PM 10 "pm10 standard" or "pm100 standard"?

alanb128, 2022-05-25:
Also confirm environmental vs. standard - which is proper to use?

alanb128, 2022-05-26:
Some details here we will use to make updates for PM performance and documentation:
https://forums.adafruit.com/viewtopic.php?f=48&t=136528#p676664
https://forums.adafruit.com/viewtopic.php?f=19&t=135496
https://www.govinfo.gov/content/pkg/FR-2020-12-18/pdf/2020-27125.pdf

alanb128, 2022-06-08:
Updated PM to use "environmental" and confirmed PM10. Updated this guide: https://balenair.com/sensors

Closed 2022-06-08.

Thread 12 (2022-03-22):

CO2 inconsistencies

alanb128, 2022-03-22:
Readings from IAQ devices next to each other with the same SCD-40 sensor can be double each other. The eCO2 can be very different as well. Look into expected sensor tolerances, calibration opportunities and other ways to mitigate large differences.

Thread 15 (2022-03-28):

If only SGP-30, use its temp and humidity

alanb128, 2022-03-28:

alanb128, 2022-07-18:
I meant SGP-30 @wjlove - corrected the title, thanks!

wjlove, 2022-07-18:
Ok, great.  I didn't think there was room for the SCD-30 to fit in the case anyway :)

Closed 2022-07-18.

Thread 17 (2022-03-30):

Bi Color Matrix Flickering

alanb128, 2022-03-30:
Under certain conditions, the LED matrix display has a sort of resonant flicker. Disassembling the case seems to improve it, so perhaps it's related to the length of I2C cable wiring. True cause is still undetermined.

alanb128, 2023-06-08:
I have traced the flicker in part to the Sparkfun qwiic multiport. If I physically jostle it, the flickering changes. Replacing the multiport also sometimes fixes the issue. I'm not sure if I had a defective one or if there is a different issue - still investigating...

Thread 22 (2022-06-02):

Provide a kit of parts for the IAQ

alanb128, 2022-06-02:
Please leave a comment in this thread if you're interested in purchasing a full kit of parts, and which sensors/displays you would like. Initially we will be selling these at/near market cost plus any shipping and handling charges. Adding a comment is not a commitment, but we will contact you if/when we start selling kits. Also let us know if you would like the 3D printed case parts as well.

PLEASE NOTE: We are currently not able to provide a Raspberry Pi in any kits.

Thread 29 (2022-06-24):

Additional/replacement sensor support

alanb128, 2022-06-24:
Considering adding [CCS811 VOC/eCO2 sensor](https://www.adafruit.com/product/3566) support due to the SGP-30 being end of life and possibly unavailable at some point.

Since the CCS811 does not have temperature readings, also consider adding BME280 or HTU-21D support as well.

wjlove, 2022-07-08:
This is a quick note to include our discussions about the SciSense ENS160 which has both eCO2 and TVOC readings and is available on a Grove compatible module.  I have complete and tested a version of iaq.py that supports this sensor and is ready for review.

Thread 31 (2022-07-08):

Suggest moving to InfluxDB 1.8.10

wjlove, 2022-07-08:
Currently we are using OSS InfluxDB 1.8.3, a bump to 1.8.10 as this *might* fix randomly dropped data issue addressed in 1.8.9 even though we currently do not use shards.

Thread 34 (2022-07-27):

Add GPIO outputs for score range

alanb128, 2022-07-27:
Use three GPIO pins on the device and use as outputs. One of the pins would go high depending on the current score range. For instance:

GPIO 16 goes high if score is high, otherwise it's low
GPIO 20 goes high if the score is in the medium range, otherwise it goes low
GPIO 21 goes high if the score is in the low range, otherwise it goes low.

These could be used for driving LEDs, relays or other outputs.

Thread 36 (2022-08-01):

Add a touch input

wjlove, 2022-08-01:
Add capacitive touch to the various device enclosures.

For the IAQ cube, modify one of the printed case components to be conductive.
For the WHAQM display, modify the side panel insert to be conductive.

For both devices, use a qwiic I2C capacitive sensor module adding about $7 to total cost.

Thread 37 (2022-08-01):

Add support for Radxa Zero device

wjlove, 2022-08-01:
Due to supply issues for the Raspi line of devices add support for other Pi Zero like devices.

Currently the first possible candidate is the Radxa Zero which already has limited support for the balenaOS.

Banana Pi Zero is also an option but currently there is limited/no support  for this devce.

wjlove, 2022-09-19:
Preliminary support for the Radxa Zero is now in balena staging with I2C support and some wifi support (specifically AP6212 chipset).

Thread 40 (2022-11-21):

Getting Connector Request Error / Cant use online dashboard

cbronner35, 2022-11-21:
Hello I'm having an issue with getting the online Grafana dashboard working again. I keep running into balena.exceptions.RequestError: b'Unauthorized' errors. I've included the logs from balena. Its important to note I did have to change the release to the latest focal build because its impossible to build under the bionic build at least for the pi0w2. Currently on the "balenaOS 2.105.21"

[airquality_grumpy-ranch-21.11.22_11_53_54_(-0500).txt](https://github.com/balenair/balenair/files/10058503/airquality_grumpy-ranch-21.11.22_11_53_54_.-0500.txt)

Thanks for any help!

mattceh, 2022-11-22:
Same here.

cbronner35, 2022-11-25:
Hey mattceh for some reason my dashboard is working again. Could you check yours to verify and I'll close this issue.

Closed 2022-11-26.

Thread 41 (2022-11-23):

Broken Grafana Connection

mattceh, 2022-11-23:
Running balenaOS 2.101.7+rev2. At first the Grafana dashboard would come up with no data (see previous issue #40). Did a redeployment and now the grafana dashboard won't load.

 dashboard  Interim dashboard sync skipped: No schema found.

logs attached.
[balenair_spring-pine-23.11.22_06_52_47_(-0700).txt](https://github.com/balenair/balenair/files/10076206/balenair_spring-pine-23.11.22_06_52_47_.-0700.txt)

Closed 2022-11-23.

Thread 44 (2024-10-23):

Issue deploying to pi zero 2 w

mattceh, 2024-10-23:
I'm getting an error when adding a device:

Step 1/7 : FROM balenalib/raspberrypi0-2w-64-ubuntu-python:3.8-bionic-build-20210826
manifest for balenalib/raspberrypi0-2w-64-ubuntu-python:3.8-bionic-build-20210826 not found: manifest unknown: manifest unknown

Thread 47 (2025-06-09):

Potential bug with MQTT

chrisys, 2025-06-09:
I'm trying to use just a username to feed MQTT to my Home Assistant instance, but it doesn't seem to work. Looking at the code there's a case on https://github.com/balenair/balenair/blob/9a46a8cbf6f3687eb4d368062cebe426846d2e58/iaq/iaq.py#L585 where it says 'if username is None and password is None' so it doesn't look like my use case would work.

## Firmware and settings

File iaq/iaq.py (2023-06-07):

# SPDX-FileCopyrightText: 2021 ladyada for Adafruit Industries SPDX-License-Identifier: MIT
# pylint: disable=unused-import
import time
import board
import busio
import json
import qwiic_led_stick
import paho.mqtt.client as mqtt
import os
import sys
import binascii
import display
import logging
from adafruit_ht16k33.matrix import Matrix8x8x2
import requests

PM25_MAX = 250
PM10_MAX = 430
CO2_MAX = 5000
PM25_RED = 55
PM10_RED = 150
CO2_RED = 2000
PM25_YELLOW = 35
PM10_YELLOW = 54
CO2_YELLOW = 1000
CO2_MIN = 400
VOC_MIN = 0
VOC_MAX = 10000
VOC_YELLOW = 500
VOC_RED = 1000

pm_sensor = True
co2_sensor = True
voc_sensor = True
use_eco2 = False
sensor_count = 0
use_tvoc = True

bar_graph = False
matrix_display = False

green_limit = 50
yellow_limit = 75

pm10_idx = 0
pm25_idx = 0
co2_idx = 0
voc_idx = 0

# Get ENV vars:

try:
    alert_mode = int(os.getenv('ALERT_MODE', '0'))
except Exception as e:
    print("Invalid value for ALERT_MODE. Using default 0.")
    alert_mode = 0

try:
    alert_level = int(os.getenv('ALERT_LEVEL', '50'))
except Exception as e:
    print("Invalid value for ALERT_LEVEL. Using default 50.")
    alert_level = 50
 
try:
    zero_bar = int(os.getenv('ZERO_BAR', '1'))
except Exception as e:
    print("Invalid value for ZERO_BAR. Using default 1.")
    zero_bar = 1
try:
    bar_mode = int(os.getenv('BAR_MODE', '1'))
except Exception as e:
    print("Invalid value for BAR_MODE. Using default 1.")
    bar_mode = 1

try:
    t = int(os.getenv('USE_TVOC', '1'))
except Exception as e:
    print("Invalid value for USE_TVOC. Using default 1.")
    use_tvoc = True
if t == 0:
    use_tvoc = False
    
try:
    log_level = os.getenv('LOG_LEVEL', 'WARNING')
except Exception as e:
    print("Invalid value for LOG_LEVEL. Using default 'WARNING'.")
    log_level = 'WARNING'
   
# Variables for optional Aggregator:
 
agg_address = os.getenv('AGG_ADDRESS', 'NONE')

try:
    agg_port = int(os.getenv('AGG_PORT', '1883'))
except Exception as e:
    print("Invalid value for AGG_PORT. Using default 1883.")
    agg_port = 1883

agg_username = os.getenv('AGG_USERNAME')

agg_password = os.getenv('AGG_PASSWORD')

agg_data = {}

#
# Get a meaningful host hame from balenaCloud device name and add it to mqtt topic, this allows easier
# grafana graphing in a multi device setup while using mqtt bridging. 
# 
try:
    r = requests.get(os.getenv('BALENA_SUPERVISOR_ADDRESS') + "/v2/device/name?apikey=" + os.getenv('BALENA_SUPERVISOR_API_KEY'))
    j = r.json()
    pretty_host_name = j["deviceName"]
except Exception as e:
    print("Unable to get deviceName via Supervisor API. Using default value.")
    pretty_host_name = "location"
pretty_host_name = pretty_host_name.replace("/", "_")
pretty_host_name = pretty_host_name.replace("'", "_")
pretty_host_name = pretty_host_name.replace("$", "_")
pretty_host_name = pretty_host_name.replace("+", "_")
pretty_host_name = pretty_host_name.replace("#", "_")
pretty_host_name = pretty_host_name.replace(" ", "_")

# Set up logger
logger = logging.getLogger('iaq_logger')
logger.setLevel(logging.DEBUG)  # Passes all messages to handlers

# Create handlers
c_handler = logging.StreamHandler(stream=sys.stdout)

if log_level == 'DEBUG':
    c_handler.setLevel(logging.DEBUG)
elif log_level == 'INFO':
    c_handler.setLevel(logging.INFO)
elif log_level == 'WARNING':
    c_handler.setLevel(logging.WARNING)
elif log_level == 'ERROR':
    c_handler.setLevel(logging.ERROR)
elif log_level == 'CRITICAL':
    c_handler.setLevel(logging.CRITICAL)
else:
    c_handler.setLevel(logging.WARNING)

print("log_level: {}".format(log_level))    
# Add handlers to the logger
logger.addHandler(c_handler)

logger.critical("You will see CRITICAL log entries.")
logger.debug("You will see DEBUG log entries.")
logger.error("You will see ERROR log entries.")
logger.warning('You will see WARNING log entries.')
logger.info("You will see INFO log entries.")

# Create library object, use 'slow' 10KHz frequency!
i2c = busio.I2C(board.SCL, board.SDA, frequency=10000)

try:
    matrix2 = Matrix8x8x2(i2c, address=0x70)
    matrix1 = Matrix8x8x2(i2c, address=0x71)
except Exception as e:
    logger.info("Only one or no LED matrix found, not using LED matrix...")
else:
    matrix_display = True

# For LED bar graph:
my_stick = qwiic_led_stick.QwiicLEDStick()
if my_stick.begin() == True:
    bar_graph = True
    time.sleep(1.5)
    try:
        my_stick.LED_off()
    except Exception as e:
        logger.info("Error accessing LED stick: {}".format(e))
else:
    logger.info("No LED stick found, not using LED stick...")

def get_reading():

    global sensor_count
    
    readings = {}

    try:
        r = requests.get('http://sensor:7575/')
    except Exception as e:
        logger.error("Error requesting sensor reading: {}".format(e))
        return readings
        
    j = r.json()

    #print("raw: {}".format(j))

    for sensor, measurement in j.items():
        #print("item: {}".format(sensor))
        if sensor == "PM25":
            readings.update(measurement)
        else:
            for key, item in measurement.items():
                #print("key: {}".format(key))
                if key == "temperature":
                    if not "temperature" in readings:
                        readings["temperature"] = item
                if key == "humidity":
                    if not "humidity" in readings:
                        readings["humidity"] = item
                if key == "CO2":
                    if not "co2" in readings:
                        sensor_count = sensor_count + 1
                        readings["co2"] = item
                if (key == "TVOC") and (use_tvoc):
                    if not "TVOC" in readings:
                        sensor_count = sensor_count + 1
                        readings["TVOC"] = item
                if key == "eCO2":
                    if not "eCO2" in readings:
                        sensor_count = sensor_count + 1
                        readings["eCO2"] = item
                        
    return readings
    #print("readings: {}".format(readings))


def pm25_index(pm25):
    #
    # Calculates our 0-99 AQ index for pm25
    #
    scaled_pm25 = 0

    if pm25 < PM25_YELLOW:
        scaler = make_interpolater(0, PM25_YELLOW, 0, 50)
        scaled_pm25 = scaler(pm25)
    elif pm25 < PM25_RED:
        scaler = make_interpolater(PM25_YELLOW, PM25_RED, 50, 75)
        scaled_pm25 = scaler(pm25)
    else:
        scaler = make_interpolater(PM25_RED, PM25_MAX, 75, 99)
        scaled_pm25 = scaler(pm25)

    if scaled_pm25 > 99:
        scaled_pm25 = 99

    return scaled_pm25

def pm10_index(pm10):
    #
    # Calculates our 0-99 AQ index for pm10
    #
    scaled_pm10 = 0

    if pm10 < PM10_YELLOW:
        scaler = make_interpolater(0, PM10_YELLOW, 0, 50)
        scaled_pm10 = scaler(pm10)
    elif pm10 < PM10_RED:
        scaler = make_interpolater(PM10_YELLOW, PM10_RED, 50, 75)
        scaled_pm10 = scaler(pm10)
    else:
        scaler = make_interpolater(PM10_RED, PM10_MAX, 75, 99)
        scaled_pm10 = scaler(pm10)

    if scaled_pm10 > 99:
        scaled_pm10 = 99
        
    return scaled_pm10

def co2_index(co2):
    #
    # Calculates our 0-99 AQ index for co2
    #
    scaled_co2 = 0

    if co2 < CO2_YELLOW:
        scaler = make_interpolater(CO2_MIN, CO2_YELLOW, 0, 50)
        scaled_co2 = scaler(co2)
    elif co2 < CO2_RED:
        scaler = make_interpolater(CO2_YELLOW, CO2_RED, 50, 75)
        scaled_co2 = scaler(co2)
    else:
        scaler = make_interpolater(CO2_RED, CO2_MAX, 75, 99)
        scaled_co2 = scaler(co2)
    
    if scaled_co2 > 99:
        scaled_co2 = 99
        
    return scaled_co2

def voc_index(voc):
    #
    # Calculates our 0-99 AQ index for VOC
    #
    scaled_voc = 0

    if voc < VOC_YELLOW:
        scaler = make_interpolater(VOC_MIN, VOC_YELLOW, 0, 50)
        scaled_voc = scaler(voc)
    elif voc < VOC_RED:
        scaler = make_interpolater(VOC_YELLOW, VOC_RED, 50, 75)
        scaled_voc = scaler(voc)
    else:
        scaler = make_interpolater(VOC_RED, VOC_MAX, 75, 99)
        scaled_voc = scaler(voc)
    
    if scaled_voc > 99:
        scaled_voc = 99

    return scaled_voc
       
def make_interpolater(left_min, left_max, right_min, right_max):
    #
    # Scales one range to another...
    # Function that returns a function (closure)
    # see https://stackoverflow.com/questions/1969240/mapping-a-range-of-values-to-another
    #

    # Figure out how 'wide' each range is  
    leftSpan = left_max - left_min  
    rightSpan = right_max - right_min  

    # Compute the scale factor between left and right values 
    scaleFactor = float(rightSpan) / float(leftSpan) 

    # create interpolation function using pre-calculated scaleFactor
    def interp_fn(value):
        return right_min + (value-left_min)*scaleFactor

    return interp_fn
    

def rotate_matrix( m ):
    #
    # Rotate digit matrix by 90 degrees counterclockwise
    # see https://stackoverflow.com/questions/53250821/in-python-how-do-i-rotate-a-matrix-90-degrees-counterclockwise
    #
    return [[m[j][i] for j in range(len(m))] for i in range(len(m[0])-1,-1,-1)]

def display_index(index_value):
    #
    # Display a two digit number on the LEDs
    #
    
    if not bar_graph and not matrix_display:
        #print("Nothing to display on...")
        return

    if bar_graph:
        logger.debug("Skipping LED matrix display...")
        bar_index(index_value)
        return
    my_color = 0
    if round(index_value) < green_limit:
        my_color = 2
    elif round(index_value) < yellow_limit:
        my_color = 3
    else:
        my_color = 1
            
    disp_val = str(round(index_value)).rjust(2)

    left_digit = disp_val[:1]
    right_digit = disp_val[-1:]

    display_led(matrix2, right_digit, my_color)
    display_led(matrix1, left_digit, my_color)
    
def display_led(my_matrix, my_value, color):
    #
    # Display a single digit
    
    if not matrix_display:
        #print("Nothing to display on...")
        return

    if my_value == ' ':
        my_digit = display.digits[0]
    else:
        my_digit = display.digits[int(my_value)]

    my_digit = rotate_matrix(my_digit)
    for x in range(8):
        for y in range(8):
            if my_digit[x][y] == 1:
                my_matrix[x,y] = color
            else:
                my_matrix[x,y] = my_matrix.LED_OFF

def display_pollutant(pm10, pm25, co2, voc):
    #
    # Display a two character icon on the LEDs
    #  representing highest-indexed pollutant
    #  Uses icons list 0,1=PM1; 2,3=PM2; 4,5=CO2
    
    if not matrix_display:
        #print("Nothing to display on...")
        return
    index_list = [pm10, pm25, co2, voc]
    max_value = max(index_list)
    max_value_index = index_list.index(max_value)
    icon_index = max_value_index * 2
        
    my_color = 0
    if round(max_value) < green_limit:
        my_color = 2
    elif round(max_value) < yellow_limit:
        my_color = 3
    else:
        my_color = 1
    display_icon(icon_index, my_color)
    
    
def display_icon(icon_index, my_color):
    #
    # Display a two character icon on the display
    # icon_index is the index of the first character
    #
    if matrix_display:
    # Loop through digits from 1 to 0
        for digit in range(1, -1, -1):
            if digit == 0:
                my_matrix = matrix1
            else:
                my_matrix = matrix2
            my_digit = display.icons[icon_index + digit]
            my_digit = rotate_matrix(my_digit)
            for x in range(8):
                for y in range(8):
                    if my_digit[x][y] == 1:
                        my_matrix[x,y] = my_color
                    else:
                        my_matrix[x,y] = my_matrix.LED_OFF

def bar_index(idx):
    #
    # Display an index on the LED bargraph
    # idx = 0 - 99
    # bar color chosen by green_limit, yellow_limit
    #
    
    if not bar_graph:
        return
    try:
        my_stick.set_all_LED_brightness(1)
    except Exception as e:
        logger.error("Trouble communicating with LED: {}".format(e))
    j = 0
    for i in range(7,-1,-1):
        time.sleep(0.25)
        j = j + 1
        seg_value_start = (j-1) * (100/8)
        seg_value_end = j * (100/8)
        if bar_mode == 2: # All LEDs same color
            if idx <= green_limit:
                my_single_LED(my_stick, i, 0, 255, 0)
            elif idx > yellow_limit:
                my_single_LED(my_stick, i, 255, 0, 0)
            else:
                my_single_LED(my_stick, i, 255, 155, 0)
        else:  # Standard bargraph
            if ((idx > seg_value_start ) and (idx <= seg_value_end)) or (idx > seg_value_end):
                if idx <= green_limit:
                    my_single_LED(my_stick, i, 0, 255, 0)
                elif idx > yellow_limit:
                    my_single_LED(my_stick, i, 255, 0, 0)
                else:
                    my_single_LED(my_stick, i, 255, 155, 0)
            else:
                if bar_mode == 1: # Fill empty segments with white (default)
                    my_single_LED(my_stick, i, 25, 25, 25)
                else:  # Turn off empty segments
                    my_single_LED(my_stick, i, 0, 0, 0)

    # Turn on first segment if idx <= 12.5 and ZERO_BAR
    if (idx <= (100/8)) and (zero_bar == 1):
        #my_stick.set_single_LED_color(7, 0, 255, 0)
        my_single_LED(my_stick, 7, 0, 255, 0)

def LED_icon(icon_num):

    # Displays rudimentary animation on LED bar graph.

    if icon_num == 1:
        # alt red/grn
        my_single_LED(my_stick, 7, 255, 0, 0)
        time.sleep(0.2)
        my_single_LED(my_stick, 6, 0, 255, 0)
        time.sleep(0.2)
        my_single_LED(my_stick, 5, 255, 0, 0)
        time.sleep(0.2)
        my_single_LED(my_stick, 4, 0, 255, 0)
        time.sleep(0.2)
        my_single_LED(my_stick, 3, 255, 0, 0)
        time.sleep(0.2)
        my_single_LED(my_stick, 2, 0, 255, 0)
        time.sleep(0.2)
        my_single_LED(my_stick, 1, 255, 0, 0)
        time.sleep(0.2)
        my_single_LED(my_stick, 0, 0, 255, 0)
        time.sleep(0.2)

    if icon_num == 2:
        # All white
        my_single_LED(my_stick, 7, 25, 25, 25)
        time.sleep(0.2)
        my_single_LED(my_stick, 6, 25, 25, 25)
        time.sleep(0.2)
        my_single_LED(my_stick, 5, 25, 25, 25)
        time.sleep(0.2)
        my_single_LED(my_stick, 4, 25, 25, 25)
        time.sleep(0.2)
        my_single_LED(my_stick, 3, 25, 25, 25)
        time.sleep(0.2)
        my_single_LED(my_stick, 2, 25, 25, 25)
        time.sleep(0.2)
        my_single_LED(my_stick, 1, 25, 25, 25)
        time.sleep(0.2)
        my_single_LED(my_stick, 0, 25, 25, 25)
        time.sleep(0.2)

def my_single_LED(stick, a, b, c, d):

    # A wrapper for set_single_LED_color() with error checking
    
    try:
        stick.set_single_LED_color(a, b, c, d)
    except Exception as e:
        logger.error("Error accessing LED: {}".format(e))
        
            
############################ START ##############################


# startup LED animation
if bar_graph:
    LED_icon(2)

# Get a reading from the sensor block, see what measurements are available
reading = get_reading()
logger.info("initial reading: {}".format(reading))

# Make sure there's at least one sensor

if sensor_count < 1:
    if bar_graph:
        LED_icon(1)
        time.sleep(5)
    else:
        display_icon(8, 1)
    logger.critical("No sensors found! Exiting...")
    sys.exit()

if ("co2" not in reading) and ("eCO2" in reading):
    # Use eCO2 for CO2
    logger.info("Using eCO2 for CO2.")
    use_eco2 = True
            
# If using matrix LEDs, display sensor icons

if "pm10 standard" in reading:
    display_icon(0, 2)
    time.sleep(2)
    display_icon(2, 2)
    time.sleep(1)
   
if "TVOC" in reading:
    display_icon(6, 2)
    time.sleep(2)
        
if ("co2" in reading) or ("eCO2" in reading):
    display_icon(4, 2)
    time.sleep(1)

# Connect to internal MQTT for onboard dashboard

client = mqtt.Client()
try:
    client.connect("mqtt", 1883, 60)
except Exception as e:
    logger.error("Error connecting to internal mqtt. ({0})".format(str(e)))
else:
    client.loop_start()

# If set, connect to Aggregator (external)

if agg_address != "NONE":
    logger.debug("Preparing connection to external MQTT address {}".format(agg_address))
    client2 = mqtt.Client()

    if (agg_username is None) and (agg_password is None):
        logger.debug("Using external MQTT username ({}) and password.".format(agg_username))
        client2.username_pw_set(agg_username, agg_password)      
    try:
        client2.connect(agg_address, agg_port, 60)
    except Exception as e:
        logger.error("Error connecting to external mqtt. ({0})".format(str(e)))
    else:
        client2.loop_start()
    
while True:
    pm = {}
    scd = {}
    voc = {}
    if ("pm10 standard" in reading) and (reading["pm10 standard"] is not None):
        logger.info("Testimg PM...")
        pm10_idx = pm10_index(reading["pm100 env"])
        pm25_idx = pm25_index(reading["pm25 env"])
    if ("co2" in reading) and (reading["co2"] is not None):
        logger.info("Testing CO2...")
        co2_idx = co2_index(reading["co2"])
    if ("TVOC" in reading) and (reading["TVOC"] is not None):
        logger.info("Testing VOC...")
        voc_idx = voc_index(reading["TVOC"])
       
    if (use_eco2) and (reading["eCO2"] is not None):
        logger.info("Using eCO2 for CO2...")
        co2_idx = co2_index(reading["eCO2"])
        reading["co2"] = reading["eCO2"]
    else:
        if (use_eco2):
            logger.debug("No eCO2 reading found and use_eco2 is True.")

    logger.debug("Scaled pm25: {0}".format(pm25_idx))
    logger.debug("Scaled pm10: {0}".format(pm10_idx))
    logger.debug("Scaled co2: {0}".format(co2_idx))
    logger.debug("Scaled voc: {0}".format(voc_idx))  
    iaq_idx = max(pm25_idx, pm10_idx, co2_idx, voc_idx)
    # Add index to dict
    reading["IAQ"] = round(iaq_idx)
    logger.debug("Using index: {0}".format(iaq_idx))
    # Display on LED matrix
    display_index(iaq_idx)
    # Publish all data to internal MQTT
    try:
        client.publish("sensors/" + pretty_host_name, json.dumps(reading))
    except Exception as e:
        logger.error("Error publishing to internal mqtt. ({0})".format(str(e)))
    
    # Publish data to external MQTT
    ret = 0
    if agg_address != "NONE":
        agg_data["device"] = pretty_host_name
        agg_data["iaq"] = round(iaq_idx)
        agg_data["dominant"] = "tbd"
        logger.debug("Sending data {0} to external MQTT address {1}".format(agg_data, agg_address))
        try:
            ret = client2.publish("sensors/" + pretty_host_name, json.dumps(agg_data))
            logger.debug("Sent external mqtt data... topic: {0}; data: {1}; return: {2}".format("sensors/" + pretty_host_name, agg_data, ret))
        except Exception as e:
            logger.error("Error publishing to external mqtt. ({0})".format(str(e)))  
    else:
        logger.debug("No external MQTT address provided.")
                
    # Alternate display with icon every 2.5 seconds if index > green_limit
    if ((iaq_idx > alert_level) and (alert_mode == 1)) or (alert_mode == 2):
    #if (1 == 1):
        time.sleep(2.5)
        for recur in range(11):
            display_pollutant(pm10_idx, pm25_idx, co2_idx, voc_idx)
            time.sleep(2.5)
            display_index(iaq_idx)
            time.sleep(2.5)
    else:
        time.sleep(55)
    
    reading = get_reading()
    logger.info("loop reading: {}".format(reading))

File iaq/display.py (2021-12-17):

digits = [[[1,1,1,1,1,1,1,0],
       [1,1,1,1,1,1,1,0],
       [1,1,0,0,0,1,1,0],
       [1,1,0,0,0,1,1,0],
       [1,1,0,0,0,1,1,0],
       [1,1,0,0,0,1,1,0],
       [1,1,1,1,1,1,1,0],
       [1,1,1,1,1,1,1,0]],      
       [[0,1,1,1,0,0,0,0],
       [0,1,1,1,0,0,0,0],
       [0,0,1,1,0,0,0,0],
       [0,0,1,1,0,0,0,0],
       [0,0,1,1,0,0,0,0],
       [0,0,1,1,0,0,0,0],
       [1,1,1,1,1,1,0,0],
       [1,1,1,1,1,1,0,0]],
       [[1,1,1,1,1,1,1,0],
       [1,1,1,1,1,1,1,0],
       [0,0,0,0,0,1,1,0],
       [1,1,1,1,1,1,1,0],
       [1,1,1,1,1,1,1,0],
       [1,1,0,0,0,0,0,0],
       [1,1,1,1,1,1,1,0],
       [1,1,1,1,1,1,1,0]],
       [[1,1,1,1,1,1,1,0],
       [1,1,1,1,1,1,1,0],
       [0,0,0,0,0,1,1,0],
       [1,1,1,1,1,1,1,0],
       [1,1,1,1,1,1,1,0],
       [0,0,0,0,0,1,1,0],
       [1,1,1,1,1,1,1,0],
       [1,1,1,1,1,1,1,0]],
       [[1,1,0,0,0,0,0,0],
       [1,1,0,1,1,0,0,0],
       [1,1,0,1,1,0,0,0],
       [1,1,1,1,1,1,1,0],
       [1,1,1,1,1,1,1,0],
       [0,0,0,1,1,0,0,0],
       [0,0,0,1,1,0,0,0],
       [0,0,0,1,1,0,0,0]],
       [[1,1,1,1,1,1,1,0],
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
 
# icons are [PM1, PM2, CO2, VOC, ??] - each two characters wide
icons = [[[1,0,0,0,0,0,0,0],
       [1,0,1,1,1,0,1,0],
       [1,0,1,0,1,0,1,1],
       [1,0,1,1,1,0,1,0],
       [1,0,1,0,0,0,1,0],
       [1,0,1,0,0,0,1,0],
       [1,0,0,0,0,0,0,0],
       [1,1,1,1,1,1,1,1]],      
       [[0,0,0,0,0,0,0,1],
       [0,0,1,0,0,1,0,1],
       [0,1,1,0,0,1,0,1],
       [1,0,1,0,0,1,0,1],
       [0,0,1,0,0,1,0,1],
       [0,0,1,0,0,1,0,1],
       [0,0,0,0,0,0,0,1],
       [1,1,1,1,1,1,1,1]],
       [[1,0,0,0,0,0,0,0],
       [1,0,1,1,1,0,1,0],
       [1,0,1,0,1,0,1,1],
       [1,0,1,1,1,0,1,0],
       [1,0,1,0,0,0,1,0],
       [1,0,1,0,0,0,1,0],
       [1,0,0,0,0,0,0,0],
       [1,1,1,1,1,1,1,1]],      
       [[0,0,0,0,0,0,0,1],
       [0,0,1,0,1,1,0,1],
       [0,1,1,0,0,1,0,1],
       [1,0,1,0,1,1,0,1],
       [0,0,1,0,1,0,0,1],
       [0,0,1,0,1,1,0,1],
       [0,0,0,0,0,0,0,1],
       [1,1,1,1,1,1,1,1]],      
       [[1,0,0,0,0,0,0,0],
       [1,0,1,1,1,0,1,1],
       [1,0,1,0,0,0,1,0],
       [1,0,1,0,0,0,1,0],
       [1,0,1,0,0,0,1,0],
       [1,0,1,1,1,0,1,1],
       [1,0,0,0,0,0,0,0],
       [1,1,1,1,1,1,1,1]],      
       [[0,0,0,0,0,0,0,1],
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
   

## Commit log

2021-09-29 Add latest STL files for case
    Change-type: patch
    [back.stl, front.stl, insulate_sense.stl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]
2021-10-01 Add error checking, index limit
    [iaq.py]
2021-10-20 Correct scaling of CO2 value
    CO2 now scales starting at 400ppm instead of 0.
    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
    [iaq.py]
2021-10-25 Change LED matrix mounting to screws
    [front.stl]
2021-10-26 Add mounting posts for SGP30
    [insulate_sense.stl]
2021-11-02 Reduce thickness of front back to 0.2mm
    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
    [front.stl]
2021-11-09 Add extra mounting hole for Qwiic Multiport
    [insulate_sense.stl]
2021-11-09 Make sensors optional
2021-12-17 Add SGP30, optional sensors
2021-12-17 Update sensor info
2022-01-01 SGP-30 calibration, LED bargraph display
2022-01-01 Create Dockerfile.raspberrypi0-2w-64
2022-01-01 Update Dockerfile.raspberrypi0-2w-64
2022-01-04 Update front case photo
2022-01-10 LED bargraph improvements
2022-01-11 Fix TVOC reporting data
    [iaq.py]
2022-02-19 Updated case, add interlocking and Pi Zero 2 mount
    Fixes #1
    Connects-to #7
    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
    [front.stl, insulate_sense.stl, pi_ring.stl]
2022-02-22 Fix logging format errors
    [iaq.py]
2022-02-24 Add stand
    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
    [stand.stl]
2022-03-23 Added bargraph brackets
    [bargraph-bracket-back.stl, bargraph-bracket-front.stl]
2022-03-30 Update iaq.py
    Added a host name to the mqtt topic and removed characters that may cause problems.
    [iaq.py]
2022-04-01 Add LED disable
2022-04-04 Update screw info.
2022-04-04 Add PM driver back in
2022-04-23 Update front to strengthen posts
    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
    [front.stl]
2022-06-08 Switch to env pm data
2022-06-21 Update iaq.py
    Allow to work without local LED displays
2022-07-07 Update iaq.py
    Fixed corrupt file
    [iaq.py]
2022-07-21 Update front pix and screw info
2023-05-30 Add sensor block, docs updates
